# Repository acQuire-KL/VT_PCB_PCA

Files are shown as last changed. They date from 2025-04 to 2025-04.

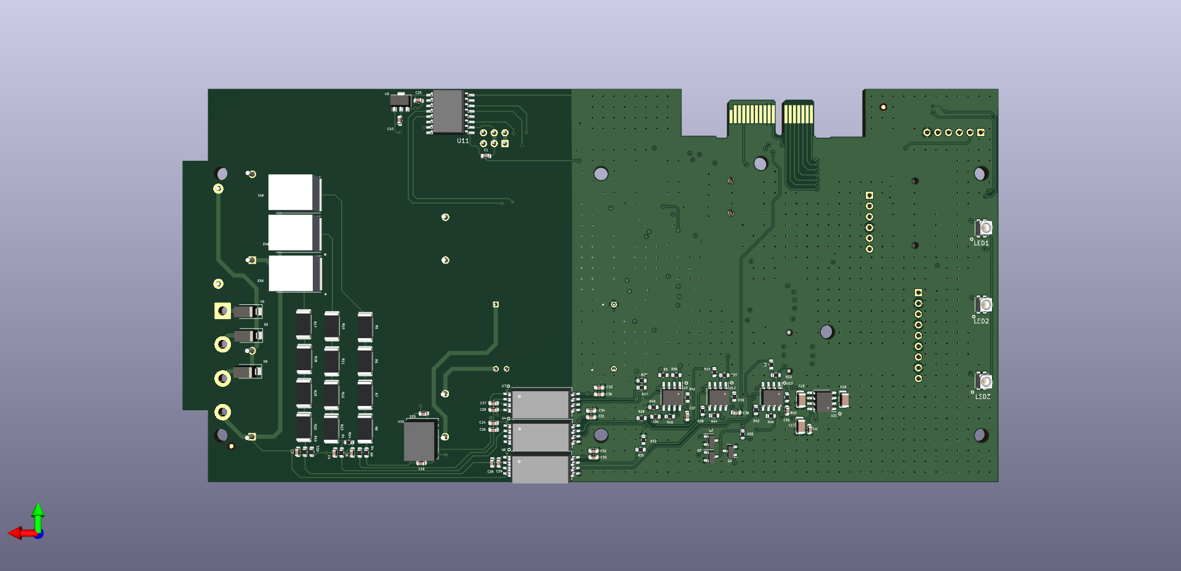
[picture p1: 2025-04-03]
_From_Cornel/H2Scan_Main_V5_4-pin - Cornel 15-04-2024/Main_V5 Cornel 15-04-2024/H2Scan_Main_v50_bottom_view.png

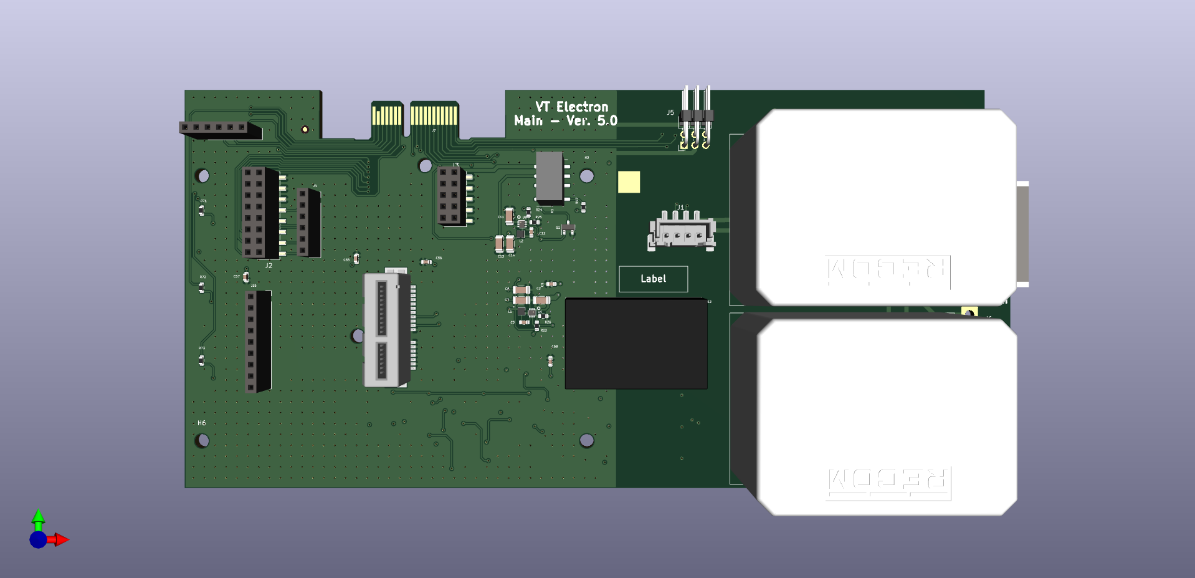
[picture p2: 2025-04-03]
_From_Cornel/H2Scan_Main_V5_4-pin - Cornel 15-04-2024/Main_V5 Cornel 15-04-2024/H2Scan_Main_v50_top_view.png

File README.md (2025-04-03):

HISTORY

<table>
  <tr>
    <td valign="top">
      Description
    </td>
    <td valign="top">
      <table border="1">
        <tr>
          <th style="font-size: 14px; font-weight: bold;">Name</th>
          <th style="font-size: 14px; font-weight: bold;">PCB</th>
          <th style="font-size: 14px; font-weight: bold;">PCA</th>
          <th style="font-size: 14px; font-weight: bold;">Date</th>
          <th style="font-size: 14px; font-weight: bold;">Comments</th>
        </tr>
        <tr>
          
          <td style="font-size: 12px;">ADE</td>
          <td style="font-size: 12px;">4901-30030-05</td>
          <td style="font-size: 12px;">3901-30030-05</td>
          <td style="font-size: 12px;">2024-09-20</td>
          <td style="font-size: 12px;">Current MFG Revisions</td>
        </tr>
        <tr>
          <td style="font-size: 12px;"></td>
          <td style="font-size: 12px;">2025-03-28</td>
          <td style="font-size: 12px;">00 --> 01 to add new circuit sections</td>
        </tr>
        <tr>
          <td style="font-size: 12px;">PCB_1001_00</td>
          <td style="font-size: 12px;">2025-03-01</td>
          <td style="font-size: 12px;">Initial release</td>
        </tr>
      </table>
    </td>
  </tr>
</table>

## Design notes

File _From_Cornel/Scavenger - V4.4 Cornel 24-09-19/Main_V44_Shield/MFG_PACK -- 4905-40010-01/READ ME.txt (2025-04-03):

PCB 4905-40010-01 is FR4, no Cu, Back Silkscreen only.

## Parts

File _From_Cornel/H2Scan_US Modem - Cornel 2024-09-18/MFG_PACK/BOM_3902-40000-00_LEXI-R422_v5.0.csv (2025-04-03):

VTPN | Reference | Value | Datasheet | Footprint | Qty | DNP
4200-00010-00 | BT1 | HLC1520-3P | ~ | Battery:HLC1520-3P | 1
4106-00080-00 | C1,C2,C3,C15 | 47p | ~ | Capacitor_SMD:C_0603_1608Metric | 4
4106-00020-00 | C4,C8,C10,C12 | 100n | ~ | Capacitor_SMD:C_0603_1608Metric | 4
4128-00100-00 | C5,C6 | TAJD477K006RNJ | ~ | Capacitor_Tantalum_SMD:CP_EIA-7361-38_AVX-V_Pad2.18x3.30mm_HandSolder | 2
4106-00070-00 | C7 | 15p | ~ | Capacitor_SMD:C_0603_1608Metric | 1
4106-00060-00 | C9 | 68p | ~ | Capacitor_SMD:C_0603_1608Metric | 1
4106-00015-00 | C11 | 10n | ~ | Capacitor_SMD:C_0603_1608Metric | 1
-- mixed values -- | C13,C14,J1 | DNP | ~ | -- mixed values -- | 3
4724-00010-00 | D1 | SMF05C.TCT |  | Diode_SMD:SC70-6 | 1
 | FID1,FID2,FID3,FID4 | Fiducial | ~ | Fiducial:Fiducial_1mm_Mask2mm | 4 | DNP
 | H1 | MountingHole | ~ | MountingHole:MountingHole_2.5mm Simpla | 1 | DNP
4402-00020-00 | J2 | Conn_02x05_Counter_Clockwise | ~ | Connector_PinHeader_2.54mm:PinHeader_2x05_P2.54mm_Vertical_SMD_MOD | 1
4402-00030-00 | J3 | Conn_02x08_Counter_Clockwise | ~ | Connector_PinHeader_2.54mm:PinHeader_2x08_P2.54mm_Vertical_SMD_MOD | 1
4753-00010-00 | J4,J5,J6 | Conn_01x01_Male | ~ | TestPoint:TestPoint_Pad_5.1x5.1mm | 3
4414-00020-00 | J11 | 78646-3001 |  | Connector_Molex:MOLEX_78646-3001 | 1
4416-00010-00 | J12 | CONUFL001-SMD-T | ~ | Connector_Coaxial:U.FL_Molex_MCRF_73412-0110_Vertical | 1
4500-00010-00 | Q3,Q8 | PDTC143XT |  | Package_TO_SOT_SMD:SOT-23 | 2
4006-00001-00 | R1,R4 | 0 | ~ | Resistor_SMD:R_0603_1608Metric | 2
4006-00020-00 | R2 | 220 | ~ | Resistor_SMD:R_0603_1608Metric | 1
4006-00150-00 | R3 | 4k7 | ~ | Resistor_SMD:R_0603_1608Metric | 1
 | TP1 | Eticheta | ~ | Symbol:Eticheta | 1 | DNP
4702-01010-00 | U1 | TPS22967DSGR | TPS22967DSGR | Package_SON:WSON-8-1EP_2x2mm_P0.5mm_EP0.9x1.6mm_ThermalVias | 1
4702-00010-00 | U2 | TXB0104RUT | http://www.ti.com/lit/ds/symlink/txb0104.pdf | Package_DFN_QFN:Texas_R_PUQFN-N12 | 1
4300-01010-00 | FB1 | FerriteBead_Small | ~ | Inductor_SMD:L_Walsin_WLFM201209x | 1
4752-01010-00 | D2 | LED | ~ | LED_SMD:LED_0805_2012Metric | 1
 | TP4 | TestPoint | ~ | TestPoint:TestPoint_Pad_D1.5mm | 1 | DNP
4716-00020-00 | M1 | LEXI-R422 |  | ublox:LEXI | 1

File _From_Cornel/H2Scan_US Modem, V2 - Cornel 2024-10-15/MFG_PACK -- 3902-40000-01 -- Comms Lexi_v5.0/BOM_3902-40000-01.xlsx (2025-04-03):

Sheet: ECO History
RefDes | VTPN | Action | ECO | Date | Description | Comment
 |  | Initial Release |  | 2024-09-20 | Initial Release of Prototype for R&D
C16 | 4106-00020-00 | Add | 24-ECO-007 | 2024-10-15 | CAP 0603 (1608_m), 100n, 10%, 16V X7R
C17 | 4106-00020-00 | Add | 24-ECO-007 | 2024-10-15 | CAP 0603 (1608_m), 100n, 10%, 16V X7R
U2 | 4702-00010-00 | Remove | 24-ECO-007 | 2024-10-15 | IC, 4-Bit Bi-Directional Tri-State Level Shifter, Auto Detect Direction, 12-UQFN
Q1 | 4500-00010-00 | Add | 24-ECO-007 | 2024-10-15 | TRN, BJT NPN - Pre-Biased R1=4K7 R2=10K, 50 V 100mA 250mW, SMD, TO-236AB (SOT-23)
Q2 | 4500-00010-00 | Add | 24-ECO-007 | 2024-10-15 | TRN, BJT NPN - Pre-Biased R1=4K7 R2=10K, 50 V 100mA 250mW, SMD, TO-236AB (SOT-23)
Q4 | 4500-00010-00 | Add | 24-ECO-007 | 2024-10-15 | TRN, BJT NPN - Pre-Biased R1=4K7 R2=10K, 50 V 100mA 250mW, SMD, TO-236AB (SOT-23)
Q5 | 4500-00010-00 | Add | 24-ECO-007 | 2024-10-15 | TRN, BJT NPN - Pre-Biased R1=4K7 R2=10K, 50 V 100mA 250mW, SMD, TO-236AB (SOT-23)
Q6 | 4500-00010-00 | Add | 24-ECO-007 | 2024-10-15 | TRN, BJT NPN - Pre-Biased R1=4K7 R2=10K, 50 V 100mA 250mW, SMD, TO-236AB (SOT-23)
PCB1 | 4902-40000-01 | Remove | 24-ECO-007 | 2024-10-15 | PCB, Scavenger GSM, U-Blox (72x25.5mm, 4-Layers, Cu, ENIG), ver 5.0
PCB1 | 4902-40000-02 | Add | 24-ECO-007 | 2024-10-15 | PCB, Scavenger GSM, U-Blox (72x25.5mm, 4-Layers, Cu, ENIG), ver 5.0.2

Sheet: Scavenger BOM
Seq | Level | VTPN | Description | ECO | Qty | UoM | RefDes | Populate | BOM Notes | Type | LifeCycle | MFG | MPN | Per Assy. | Unit € | Value € | Vendor | Parts Master Notes | MOQ | Pack Qty | LT
1 | Parent | 3902-40000-01 | PCA, Scavenger - Communications (GSM), U-Blox Lexi, Ver 5.0 | 24-ECO-007 | 1 | ea |  |  |  | Make | Obsolete | ECAS | 0.00 | 1 | 0.0000 | 21.7220 |  | 0.0000 | 0 | 0 | 0
2 | 1 | 4200-00020-00 | CAP, 3v7 39mAh Hybrid Layer Capacitor, 15x20, 3-pin Solder Tags |  | 1 | ea | BT1 |  |  | Buy | Production | LongSing Technology | HPC-1520 | 1 | 2.6969 | 2.6969 | LongSing Technology Group | 0.0000 | 500 | 500 | 0
3 | 1 | 4106-00080-00 | CAP 0603 (1608_m), 47p, 5%, 50V C0G |  | 4 | ea | C1,C2,C3,C15 |  |  | Buy | Production | Walsin | 0603N470J500CT | 4 | 0.0046 | 0.0184 | 0.0000 | 0.0000 | 4000 | 4000 | 0
4 | 1 | 4106-00020-00 | CAP 0603 (1608_m), 100n, 10%, 16V X7R | 24-ECO-007 | 6 | ea | C4,C8,C10,C12,C16,C17 |  |  | Buy | Production | Darfon | C1005X7R104KETS | 6 | 0.0005 | 0.0029 | Schukat | 0.0000 | 4000 | 4000 | 0
5 | 1 | 4128-00100-00 | CAP 2917 (7343_m), 470u, 10%, 6v3 Tant |  | 2 | ea | C5,C6 |  |  | Buy | Production | Kyocera AVX | TAJD477K006RNJ | 2 | 0.5600 | 1.1200 | ECAS | 0.0000 | 500 | 500 | 0
6 | 1 | 4106-00070-00 | CAP 0603 (1608_m), 15p, 5%, 50V C0G |  | 1 | ea | C7 |  |  | Buy | Production | Walsin | 0603N150J500CT | 1 | 0.0044 | 0.0044 | 0.0000 | 0.0000 | 4000 | 4000 | 0
7 | 1 | 4106-00060-00 | CAP 0603 (1608_m), 68p, 5%, 50V C0G |  | 1 | ea | C9 |  |  | Buy | Production | Samsung | CL10C680JB8NNNC | 1 | 0.0074 | 0.0074 | 0.0000 | 0.0000 | 4000 | 4000 | 0
8 | 1 | 4106-00015-00 | CAP 0603 (1608_m), 10n, 10%, 50V X7R |  | 1 | ea | C11 |  |  | Buy | Production | Darfon | C1608X7R103KGTS | 1 | 0.0021 | 0.0021 | Schukat | 0.0000 | 4000 | 4000 | 0
9 | 1 | 4106-00000-00 | CAP 0603 Place Holder |  | 2 | ea | C13,C14 | DNP |  | Reference Item | Production | None | None | 2 | 0.0000 |  |  | 0.0000 | 0 | 0 | 0
10 | 1 | 4724-00010-00 | TVS, 5-Ch, 12.5V Clamp 8A (8/20µs) Ipp, SC-70-6 |  | 1 | ea | D1 |  |  | Buy | Production | Semtech | SMF05C.TCT | 1 | 0.2448 | 0.2448 | ECAS | 0.0000 | 3000 | 0 | 0
11 | 1 | 4752-01010-00 | LED, Green 523nm, 3.2V, 0805 (2012 Metric) |  | 1 | ea | D2 |  |  | Buy | Production | Dialight | 598-8181-102F | 1 | 0.4775 | 0.4775 | 0.0000 | 0.0000 | 100 | 1 | 0
12 | 1 | 4300-01010-00 | FB, 220 Ohms, Ferrite Bead, 0603 (1608 Metric), 2A 50mOhm |  | 1 | ea | FB1 |  |  | Buy | Production | Murata | BLM18EG221SN1D | 1 | 0.0526 | 0.0526 | 0.0000 | 0.0000 | 4000 | 4000 | 0
13 | 1 | 4000-00000-00 | Test point / Mounting Hole / Fudicials / Non Component on PCB |  | 4 | ea | FID1,FID2,FID3,FID4 | DNP |  | Reference Item | Production | none | none | 4 | 0.0000 |  |  | 0.0000 | 0 | 0 | 0
14 | 1 | 4000-00000-00 | Test point / Mounting Hole / Fudicials / Non Component on PCB |  | 1 | ea | H1 | DNP |  | Reference Item | Production | none | none | 1 | 0.0000 |  |  | 0.0000 | 0 | 0 | 0
15 | 1 | 4402-00020-00 | CON, 2x5-pin, Straight, SMD, B2B Male Header, P=2.54mm, 3A |  | 1 | ea | J2 |  |  | Buy | Production | Amphenol FCI | 95278-102B10LF | 1 | 0.3668 | 0.3668 | ECAS | 0.0000 | 5000 | 0 | 0
16 | 1 | 4402-00030-00 | CON, 2x8-pin, Straight, SMD, B2B Male Header, P=2.54mm, 3A |  | 1 | ea | J3 |  |  | Buy | Production | Amphenol FCI | 95278-102B16LF | 1 | 0.4309 | 0.4309 | ECAS | 0.0000 | 1 | 0 | 0
17 | 1 | 4753-00010-00 | HDW, Cable Clamp, SMD, 5x5x2mm, Ø1.0 ~ 1.5mm |  | 3 | ea | J4,J5,J6 |  | • Pay attention to orientation as it is possible to have four. | Buy | Production | Harwin | S8111-46R | 3 | 0.1331 | 0.3994 | Digikey | 0.0000 | 1500 | 1500 | 0
18 | 1 | 4414-00020-00 | CON, 6-Pos MicroSIM Cage, Push-Pull, No Detect, SMD |  | 1 | ea | J11 |  |  | Buy | Production | Molex | 78646-3001 | 1 | 0.7900 | 0.7900 | ECAS | RFQ before next build | 57 | 1 | 0
19 | 1 | 4416-00010-00 | CON, U.FL (UMCC) Jack, Male Pin 50Ohm SMD |  | 1 | ea | J12 |  |  | Buy | Production | TE Connectivity | 2337019-1 | 1 | 0.0061 | 0.0061 | ECAS | 0.0000 | 55 | 1 | 0
20 | 1 | 4716-00020-00 | MDM, Cellular, LTE-M and NBIoT module with 2G fallback for global use, 133 pin LGA |  | 1 | ea | M1 |  | • Pay attention to orientation as it is possible to have four. | Buy | Production | u-Blox | LEXI-R422-01B-00 | 1 | 14.3653 | 14.3653 | Alpha Micro | 0.0000 | 1000 | 1000 | 0
21 | 1 | 4500-00010-00 | TRN, BJT NPN - Pre-Biased R1=4K7 R2=10K, 50 V 100mA 250mW, SMD, TO-236AB (SOT-23) | 24-ECO-007 | 3 | ea | Q1,Q3,Q8 |  |  | Buy | Production | Nexperia | PDTC143XT | 3 | 0.0270 | 0.0811 | ECAS | 0.0000 | 3000 | 0 | 0
22 | 1 | 4500-00010-00 | TRN, BJT NPN - Pre-Biased R1=4K7 R2=10K, 50 V 100mA 250mW, SMD, TO-236AB (SOT-23) | 24-ECO-007 | 4 | ea | Q2,Q4,Q5,Q6 |  |  | Buy | Production | Nexperia | PDTC143XT | 4 | 0.0270 | 0.1082 | ECAS | 0.0000 | 3000 | 0 | 0
23 | 1 | 4006-00001-00 | RES 0603 (1608_m), 0R (Jumper), 1%, 1/10W, Thick Film |  | 2 | ea | R1,R4 |  |  | Buy | Production | Vishay Dale | CRCW06030000Z0EA | 2 | 0.0009 | 0.0018 | Schukat | 0.0000 | 5000 | 5000 | 0
24 | 1 | 4006-00020-00 | RES 0603 (1608_m), 220R, 1%, 1/10W, Thick Film |  | 1 | ea | R2 |  |  | Buy | Production | Vishay | CRCW0603220RFKEA | 1 | 0.0010 | 0.0010 | ECAS | 0.0000 | 5000 | 0 | 0
25 | 1 | 4006-00150-00 | RES 0603 (1608_m), 4K7, 1%, 1/10W, Thick Film |  | 1 | ea | R5 |  |  | Buy | Production | Vishay | CRCW06034K70FKEA | 1 | 0.0012 | 0.0012 | Schukat | 0.0000 | 5000 | 5000 | 0
26 | 1 | 4006-00170-00 | RES 0603 (1608_m), 10K, 1%, 1/10W, Thick Film |  | 4 | ea | R6,R7,R8,R9 |  |  | Buy | Production | Vishay | CRCW060310K0FKEA | 4 | 0.0005 | 0.0019 | Schukat | 0.0000 | 5000 | 5000 | 0
27 | 1 | 4000-00000-00 | Test point / Mounting Hole / Fudicials / Non Component on PCB |  | 1 | ea | TP1 | DNP |  | Reference Item | Production | none | none | 1 | 0.0000 |  |  | 0.0000 | 0 | 0 | 0
28 | 1 | 4000-00000-00 | Test point / Mounting Hole / Fudicials / Non Component on PCB |  | 1 | ea | TP4 | DNP |  | Reference Item | Production | none | none | 1 | 0.0000 |  |  | 0.0000 | 0 | 0 | 0
29 | 1 | 4702-01010-00 | IC, Power Switch/Driver 1:1 N-Channel 4A 8-WSON (2x2) |  | 1 | ea | U1 |  |  | Buy | Production | TI | TPS22967DSGT | 1 | 0.5414 | 0.5414 | 0.0000 | 0.0000 | 250 | 250 | 0
30 | 1 | 4902-40000-02 | PCB, Scavenger GSM, U-Blox (72x25.5mm, 4-Layers, Cu, ENIG), ver 5.0.2 | 24-ECO-007 | 1 | ea | PCB1 |  |  | Buy | Obsolete | EMS Approved | 0.00 | 1 | 0.9200 | 0.9200 | 0.0000 | 0.0000 | 0 | 0 | 0

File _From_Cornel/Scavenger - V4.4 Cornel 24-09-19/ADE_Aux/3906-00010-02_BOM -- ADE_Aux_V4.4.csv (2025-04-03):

Reference | VTPN | Value | Datasheet | Footprint | Qty | DNP
FID1,FID2,FID3,FID4 | 4000-00000-00 | Fiducial | ~ | Fiducial:Fiducial_1mm_Mask2mm | 4 | DNP
J2 | 4000-00000-00 | Bus_PCI_Express_x1_MOD | http://www.ritrontek.com/uploadfile/2016/1026/20161026105231124.pdf#page=63 | Connector_PCBEdge:BUS_PCIexpress_x1 | 1 | DNP
J15 | 4000-00000-00 | MUAS100-8-C-E | ~ | Connector_PinHeader_2.54mm:PinHeader_1x08_P2.54mm_Vertical | 1 | DNP
TP1 | 4000-00000-00 | Eticheta | ~ | Symbol:Eticheta | 1 | DNP
C4,C8,C10,C12 | 4004-00000-00 | DNP | ~ | Capacitor_SMD:C_0402_1005Metric | 4
R3,R5,R7,R8,R11,R13,R15,R16,R17,R19,R20,R21 | 4004-00001-00 | 0 | ~ | Resistor_SMD:R_0402_1005Metric | 12
R1,R2 | 4004-00010-00 | 1k | ~ | Resistor_SMD:R_0402_1005Metric | 2
R4,R10,R12,R14 | 4004-00020-00 | 100 | ~ | Resistor_SMD:R_0402_1005Metric | 4
R6,R9,R18,R22,R27 | 4004-00100-00 | 30K | ~ | Resistor_SMD:R_0402_1005Metric | 5
R23,R24,R25,R26 | 4004-02000-00 | 137K | ~ | Resistor_SMD:R_0402_1005Metric | 4
C1,C3,C7,C9,C11 | 4104-00020-00 | 22n | ~ | Capacitor_SMD:C_0402_1005Metric | 5
C2,C5,C6,C13,C14,C15,C16,C17,C19,C21,C23,C27,C28,C29,C30,C31 | 4104-00100-00 | 100n | ~ | Capacitor_SMD:C_0402_1005Metric | 16
C18,C20,C22,C24,C25,C26 | 4112-00100-00 | 10u | ~ | Capacitor_SMD:C_1206_3216Metric | 6
J1 | 4408-00010-00 | MUAS100-8-C-E | ~ | Connector_JST:A2501-SR08-XH8AWB | 1
U4 | 4520-00030-00 | MC7660DR2 | http://www.ti.com/lit/ds/symlink/lmc7660.pdf | Package_SO:SO-8_3.9x4.9mm_P1.27mm | 1
U2 | 4706-00030-00 | ADE9430 |  | Package_QFP:ADE9430 | 1
U1,U3 | 4708-00010-00 | TLV2186IDSGR | -- mixed values -- | Package_SON:WSON-8-1EP_2x2mm_P0.5mm_EP0.9x1.6mm_ThermalVias | 2
Y2 | 4712-00020-00 | ECS-5032MV-245.7-BN-TR |  | Oscillator:OSC_ECS-5032MV-245.7-BN-TR | 1
U99 | 4726-00010-00 | NC7SZ126M5X |  | Buffer3S:Buffer3S | 1

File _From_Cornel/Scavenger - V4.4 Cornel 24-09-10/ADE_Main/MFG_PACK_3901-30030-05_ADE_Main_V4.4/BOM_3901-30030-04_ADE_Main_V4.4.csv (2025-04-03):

VTPN | Reference | Value | Datasheet | Footprint | Qty | DNP
4104-00020-00 | C1,C3,C7,C9,C11 | 22n | ~ | Capacitor_SMD:C_0402_1005Metric | 5
4112-00100-00 | C18,C20,C22,C24,C25,C26 | 10u | ~ | Capacitor_SMD:C_1206_3216Metric | 6
-- mixed values -- | C2,C5,C6,C13,C14,C15,C16,C17,C19,C21,C23,C27,C28,C29,C30 | 100n | ~ | -- mixed values -- | 15
4104-00000-00 | C4,C8,C10,C12 | DNP | ~ | Capacitor_SMD:C_0402_1005Metric | 4
 | FID1,FID2,FID3,FID4 | Fiducial | ~ | Fiducial:Fiducial_1mm_Mask2mm | 4
 | J2 | Bus_PCI_Express_x1_MOD | http://www.ritrontek.com/uploadfile/2016/1026/20161026105231124.pdf#page=63 | Connector_PCBEdge:BUS_PCIexpress_x1 | 1
4408-00010-00 | J1,J15 | MUAS100-8-C-E | ~ | -- mixed values -- | 2
4004-00010-00 | R1,R2 | 1k | ~ | Resistor_SMD:R_0402_1005Metric | 2
4004-02000-00 | R23,R24,R25,R26 | 137K | ~ | Resistor_SMD:R_0402_1005Metric | 4
4004-00001-00 | R3,R5,R7,R8,R11,R13,R15,R16,R17,R19,R20,R21 | 0 | ~ | Resistor_SMD:R_0402_1005Metric | 12
4004-00020-00 | R4,R10,R12,R14 | 100 | ~ | Resistor_SMD:R_0402_1005Metric | 4
4004-00100-00 | R6,R9,R18,R22 | 30K | ~ | Resistor_SMD:R_0402_1005Metric | 4
 | TP1 | Eticheta | ~ | Symbol:Eticheta | 1
4706-00030-00 | U2 | ADE9430 |  | Package_QFP:ADE9430 | 1
4520-00030-00 | U4 | MC7660DR2 | http://www.ti.com/lit/ds/symlink/lmc7660.pdf | Package_SO:SO-8_3.9x4.9mm_P1.27mm | 1
4708-00010-00 | U1,U3 | TLV2186IDSGR | -- mixed values -- | Package_SON:WSON-8-1EP_2x2mm_P0.5mm_EP0.9x1.6mm_ThermalVias | 2
4712-00020-00 | Y2 | ECS-5032MV-245.7-BN-TR |  | Oscillator:OSC_ECS-5032MV-245.7-BN-TR | 1

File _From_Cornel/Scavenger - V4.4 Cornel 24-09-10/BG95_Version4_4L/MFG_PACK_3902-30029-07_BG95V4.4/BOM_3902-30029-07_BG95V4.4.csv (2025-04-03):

VTPN | Reference | Value | Datasheet | Footprint | Qty | DNP
4200-00020-00 | BT1 | HLC1520-3P | ~ | Battery:HLC1520-3P | 1
4106-00040-00 | C1,C2,C3,C9,C10 | 33p | ~ | -- mixed values -- | 5
4106-00020-00 | C4,C7,C8 | 100n | ~ | -- mixed values -- | 3
4128-00100-00 | C5,C6 | TAJD477K006RNJ | ~ | Capacitor_Tantalum_SMD:CP_EIA-7361-38_AVX-V_Pad2.18x3.30mm_HandSolder | 2
4106-00010-00 | C11,C12 | 10p | ~ | Capacitor_SMD:C_0603_1608Metric_Pad1.05x0.95mm_HandSolder | 2
-- mixed values -- | C13,C14,J1 | DNP | ~ | -- mixed values -- | 3
4724-00010-00 | D1 | SMF05C.TCT |  | Diode_SMD:SC70-6 | 1
 | FID1,FID2,FID3,FID4 | Fiducial | ~ | Fiducial:Fiducial_1mm_Mask2mm | 4 | DNP
 | H1 | MountingHole | ~ | MountingHole:MountingHole_2.5mm Simpla | 1 | DNP
4402-00020-00 | J2 | Conn_02x05_Counter_Clockwise | ~ | Connector_PinHeader_2.54mm:PinHeader_2x05_P2.54mm_Vertical_SMD_MOD | 1
4402-00030-00 | J3 | Conn_02x08_Counter_Clockwise | ~ | Connector_PinHeader_2.54mm:PinHeader_2x08_P2.54mm_Vertical_SMD_MOD | 1
4753-00010-00 | J4,J5,J6 | Conn_01x01_Male | ~ | TestPoint:TestPoint_Pad_5.1x5.1mm | 3
4414-00020-00 | J11 | 78646-3001 |  | Connector_Molex:MOLEX_78646-3001 | 1
4416-00010-00 | J12 | CONUFL001-SMD-T | ~ | Connector_Coaxial:U.FL_Molex_MCRF_73412-0110_Vertical | 1
4500-00010-00 | Q1,Q3,Q8 | PDTC143XT |  | Package_TO_SOT_SMD:SOT-23 | 3
4530-00010-00 | Q2 | AO4459 | https://www.onsemi.com/pub/Collateral/FDS9435A-D.PDF | Package_SO:SOIC-8_3.9x4.9mm_P1.27mm | 1
4006-00160-00 | R1 | 15k | ~ | Resistor_SMD:R_0603_1608Metric | 1
4006-00150-00 | R2,R3 | 4k7 | ~ | Resistor_SMD:R_0603_1608Metric | 2
4006-00001-00 | R4 | 0 | ~ | Resistor_SMD:R_0603_1608Metric | 1
 | TP1 | Eticheta | ~ | Symbol:Eticheta | 1 | DNP
4716-00010-00 | U1 | BG95 | 1.1 | BG95:XCVR_BG95M3LA-64-SGNS | 1
4702-00010-00 | U2 | TXB0104RUT | http://www.ti.com/lit/ds/symlink/txb0104.pdf | Package_DFN_QFN:Texas_R_PUQFN-N12 | 1

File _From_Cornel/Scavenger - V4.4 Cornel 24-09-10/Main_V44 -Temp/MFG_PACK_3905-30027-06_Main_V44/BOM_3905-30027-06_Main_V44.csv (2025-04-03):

VTPN | Reference | Value | Datasheet | Footprint | Qty | DNP
4106-00020-00 | C1,C3,C5,C10,C12,C15,C20,C21,C24,C25,C27,C28,C29,C33,C34,C35,C36,C37,C38,C39,C40,C43,C47,C48,C49,C50,C55,C56,C57,C58 | 100n | ~ | Capacitor_SMD:C_0603_1608Metric | 30
4112-00110-00 | C2,C11,C53 | 10uF/16V | ~ | Capacitor_SMD:C_1206_3216Metric | 3
4106-00030-00 | C4,C6,C7 | 1n | ~ | Capacitor_SMD:C_0603_1608Metric | 3
4112-00150-00 | C8,C9,C13,C14 | 22uF/6,3V | ~ | Capacitor_SMD:C_1206_3216Metric | 4
4112-00100-00 | C17,C18,C19 | 10u | ~ | Capacitor_SMD:C_1206_3216Metric | 3
4106-00100-00 | C22,C23,C26,C30,C31,C32 | 1uF | ~ | Capacitor_SMD:C_0603_1608Metric | 6
4106-00010-00 | C41,C44 | 10p | ~ | Capacitor_SMD:C_0603_1608Metric | 2
4106-00100-00 | C42 | 1u | ~ | Capacitor_SMD:C_0603_1608Metric | 1
4106-00015-00 | C45,C46 | 10n | ~ | Capacitor_SMD:C_0603_1608Metric | 2
4106-00050-00 | C51 | 4,7n | ~ | Capacitor_SMD:C_0603_1608Metric | 1
4130-00010-00 | C52 | F862DI224K310ZLH0J | ~ | Capacitor_THT:C_Rect_L24.0mm_W7.0mm_P22.50mm_MKT | 1
4510-00010-00 | D4,D5,D6 | BYG21M-E3/TR | ~ | Diode_SMD:D_SMA | 3
 | FID1,FID2,FID3,FID4 | Fiducial | ~ | Fiducial:Fiducial_1mm_Mask2mm | 4 | DNP
 | H1,H2,H3,H4,H5,H6,H7,H8,H9,H10,H11,H12 | MountingHole | ~ | -- mixed values -- | 12 | DNP
4408-00030-00 | J1 | Conn_01x04_Male | ~ | Connector_JST:A2501-SR04-XH4AWB | 1
4402-10021-00 | J2 | Conn_02x08_Counter_Clockwise | ~ | Connector_PinSocket_2.54mm:PinSocket_2x08_P2.54mm_Vertical_SMD_MOD | 1
4402-10011-00 | J3 | Conn_02x05_Counter_Clockwise | ~ | Connector_PinSocket_2.54mm:PinSocket_2x05_P2.54mm_Vertical_SMD | 1
4401-00050-00 | J4,J13 | Conn_01x06_Female | ~ | Connector_PinSocket_2.54mm:PinSocket_1x06_P2.54mm_Vertical | 2
4400-00015-00 | J5 | DS1022-2*10RF11x3 | ~ | Connector_PinHeader_2.54mm:PinHeader_2x03_P2.54mm_Horizontal | 1
 | J6,J8,J9,J10,J11,J12,J14,J16,J17,J18,J19,J20,J22,J23,J24,J25,J26,J32 | Conn_01x01_Female | ~ | -- mixed values -- | 18 | DNP
 | J7 | Bus_PCI_Express_x1_MOD | http://www.ritrontek.com/uploadfile/2016/1026/20161026105231124.pdf#page=63 | Connector_PCBEdge:BUS_PCIexpress_x1 | 1 | DNP
4412-00040-00 | J15 | DS1002-03-1*36131(9) | ~ | Connector_PinSocket_2.54mm:PinSocket_1x09_P2.54mm_Vertical | 1
4401-00040-00 | J21 | Conn_01x03_Male | ~ | Connector_PinHeader_2.54mm:PinHeader_1x03_P2.54mm_Vertical | 1
4420-20010-00 | J27,J28 | Conn_01x02_Female | ~ | TerminalBlock:TerminalBlock_bornier-2_P5.08mm | 2
4753-00010-00 | J29,J30,J31 | Conn_01x01_Male | ~ | TestPoint:TestPoint_Pad_5.1x5.1mm | 3
4750-00010-00 | K1 | FTR-B4GA003Z-B05 | https://www.fujitsu.com/downloads/MICRO/fcai/relays/ftr-f1.pdf | Relay_SMD:Relay_Fujitsu_FTR-B4GA003 | 1
4300-00010-00 | L1,L2 | 744383130033 |  | Inductanta744:744383130033 | 2
4300-00020-00 | L3 | CBC3225T220MR | ~ | Inductor_SMD:L_1206_3216Metric | 1
4752-00010-00 | LED1,LED2,LED3 | CLM2D-GPC-CB0E0793 |  | LedSMD_Cree:CLM2D-GPC-CB0E0793 | 3
4520-30010-00 | PS1 | RAC15-05SK/480 |  | RAC15:CONV_RAC15-12SK_480 | 1
4520-20010-00 | PS2 | THM_10-0511 |  | THM 10-0511:CONV_THM_10-0511 | 1
4520-20022-00 | PS3 | NXE2S0505MC-R7 | NXE2S0505MC-R7 | NXE2S0505MC-R7:NXE2_SINGLE_SURFACE_MUR | 1
4500-00020-00 | Q1 | DTC143T |  | Package_TO_SOT_SMD:SOT-23 | 1
4500-00010-00 | Q2,Q3,Q4 | DTC143E |  | Package_TO_SOT_SMD:SOT-23 | 3
4006-00030-00 | R1,R4,R16 | 10 | ~ | Resistor_SMD:R_0603_1608Metric | 3
4006-00300-00 | R2,R3,R15,R22,R27,R28,R29,R30,R31,R32,R36,R37,R38,R39,R40,R41,R42,R43,R48,R49,R50 | 3k | ~ | Resistor_SMD:R_0603_1608Metric | 21
4018-01000-00 | R5,R6,R7,R8,R10,R11,R12,R13,R17,R18,R19,R20 | 249k | ~ | Resistor_SMD:R_2512_6332Metric | 12
4006-00040-00 | R9,R14,R21 | 150 | ~ | Resistor_SMD:R_0603_1608Metric | 3
4006-00150-00 | R23,R24 | 4k7 | ~ | Resistor_SMD:R_0603_1608Metric | 2
4006-00130-00 | R25 | 1k3 | ~ | Resistor_SMD:R_0603_1608Metric | 1
4006-00140-00 | R26 | 1k5 | ~ | Resistor_SMD:R_0603_1608Metric | 1
4006-00470-00 | R33 | 47k | ~ | Resistor_SMD:R_0603_1608Metric | 1
4006-00200-00 | R34,R51,R52,R53 | 2k 0.1% | ~ | Resistor_SMD:R_0603_1608Metric | 4
4006-00100-00 | R35 | 1k | ~ | Resistor_SMD:R_0603_1608Metric | 1
4006-00160-00 | R44,R45,R46 | 15k | ~ | Resistor_SMD:R_0603_1608Metric | 3
4006-00010-00 | R47 | 47 | ~ | Resistor_SMD:R_0603_1608Metric | 1
4006-00020-00 | R71,R72,R73 | 220 | ~ | Resistor_SMD:R_0603_1608Metric | 3
4022-00010-00 | RV1,RV2,RV3 | MOVS4032V510 | ~ | MOVS4032V510:MOVS4032V460 | 3
 | TP1 | Eticheta | ~ | Symbol:Eticheta | 1 | DNP
4520-10010-00 | U1,U8 | AP62250Z6 | https://www.diodes.com/assets/Datasheets/AP62250.pdf | Package_TO_SOT_SMD:SOT-563 | 2
4700-00010-00 | U2 | ISO3082DW | http://www.ti.com/lit/ds/symlink/iso3082.pdf | Package_SO:SOIC-16W_7.5x10.3mm_P1.27mm | 1
4708-00021-00 | U3,U12,U13 | LM358 | http://www.ti.com/lit/ds/symlink/lm2904-n.pdf | Package_SO:SO-8_3.9x4.9mm_P1.27mm | 3
4710-00010-00 | U4,U6,U7 | AMC1400QDWLRQ1 |  | AMC1400:AMC1400QDWLRQ1 | 3
4522-00010-00 | U5 | L78L05ACUTR | http://www.st.com/content/ccc/resource/technical/document/datasheet/15/55/e5/aa/23/5b/43/fd/CD00000446.pdf/files/CD00000446.pdf/jcr:content/translations/en.CD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 | Package_TO_SOT_SMD:SOT-89-3 | 1
4700-00030-00 | U9 | 74LVC2G157 | http://www.ti.com/lit/sg/scyt129e/scyt129e.pdf | Package_SO:VSSOP-8_2.4x2.1mm_P0.5mm | 1
4706-00040-00 | U11,U20 | MAX31865ATP+T | MAX31865ATP+T | MAX31865:21-0140L_T2055-5_MXM | 2
4410-00010-00 | U14,U15,U16,U17,U18,U19 | 10061913-100CLF |  | PCI_SMD_MOD:10061913-100CLF | 6
4520-00020-01 | U21 | LM2662MX | http://www.ti.com/lit/ds/symlink/lmc7660.pdf | Package_SO:SO-8_3.9x4.9mm_P1.27mm | 1
4704-00020-00 | U22 | MSP430FR2672TRHBR | MSP430FR2672TRHBR | MSP430FR2672TRHBR:VQFN32_5X5_TEX | 1
4714-00010-00 | Y1 | ECS-.327-6-34B-C-TR | ~ | Crystal:Crystal_SMD_EuroQuartz_EQ161-2Pin_3.2x1.5mm | 1

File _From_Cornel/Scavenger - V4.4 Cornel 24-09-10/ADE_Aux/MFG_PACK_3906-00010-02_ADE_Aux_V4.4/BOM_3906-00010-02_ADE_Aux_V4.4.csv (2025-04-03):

Id | Designator | Footprint | Quantity | Designation | Supplier and ref
1 | R25,R26,R24,R23 | R_0402_1005Metric | 4 | 137K
2 | R18,R9,R6,R22,R27 | R_0402_1005Metric | 5 | 30K
3 | R5,R20,R8,R11,R15,R21,R17,R7,R16,R3,R19,R13 | R_0402_1005Metric | 12 | 0
4 | C11,C3,C7,C9,C1 | C_0402_1005Metric | 5 | 22n
5 | C13,C16,C6,C5,C31,C28,C30,C23,C15,C27,C17,C14,C29,C19,C21 | C_0402_1005Metric | 15 | 100n
6 | FID1,FID4,FID3,FID2 | Fiducial_1mm_Mask2mm | 4 | Fiducial
7 | C26,C18,C25,C20,C22,C24 | C_1206_3216Metric | 6 | 10u
8 | C2 | C_0603_1608Metric | 1 | 100n
9 | C4,C12,C10,C8 | C_0402_1005Metric | 4 | DNP
10 | TP1 | Eticheta | 1 | Eticheta
11 | R4,R14,R10,R12 | R_0402_1005Metric | 4 | 100
12 | U3,U1 | WSON-8-1EP_2x2mm_P0.5mm_EP0.9x1.6mm_ThermalVias | 2 | TLV2186IDSGR
13 | U2 | ADE9430 | 1 | ADE9430
14 | R2,R1 | R_0402_1005Metric | 2 | 1k
15 | U99 | Buffer3S | 1 | NC7SZ126M5X
16 | Y2 | OSC_ECS-5032MV-245.7-BN-TR | 1 | ECS-5032MV-245.7-BN-TR
17 | J1 | A2501-SR08-XH8AWB | 1 | MUAS100-8-C-E
18 | J15 | PinHeader_1x08_P2.54mm_Vertical | 1 | MUAS100-8-C-E
19 | J2 | BUS_PCIexpress_x1 | 1 | Bus_PCI_Express_x1_MOD
20 | U4 | SO-8_3.9x4.9mm_P1.27mm | 1 | MC7660DR2

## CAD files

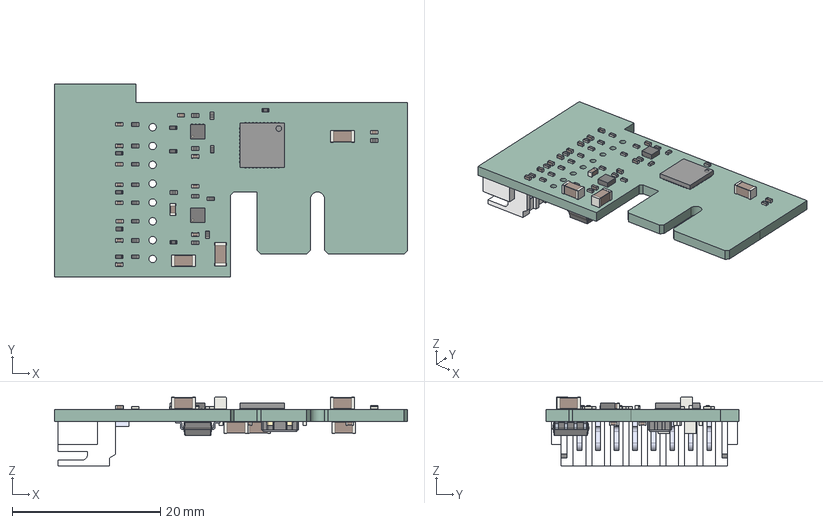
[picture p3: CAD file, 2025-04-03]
_From_Cornel/Scavenger - V4.4 Cornel 24-08-31/Scavenger- V4.4/ADE_Main/4901-30030-05 -- ADE_Main_V4.step
47.6 x 26.0 x 9.25 mm
R_0402_1005Metric x 26
C_0402_1005Metric x 23
C_1206_3216Metric x 6
C_0603_1608Metric
WSON_8_1EP_2x2mm_P05mm_EP09x16mm x 2
ASSEMBLY
ECS-3961slash3963
A2501WR-8P1--3D SMD v2
CQ assembly
ADE_Main_V4_PCB

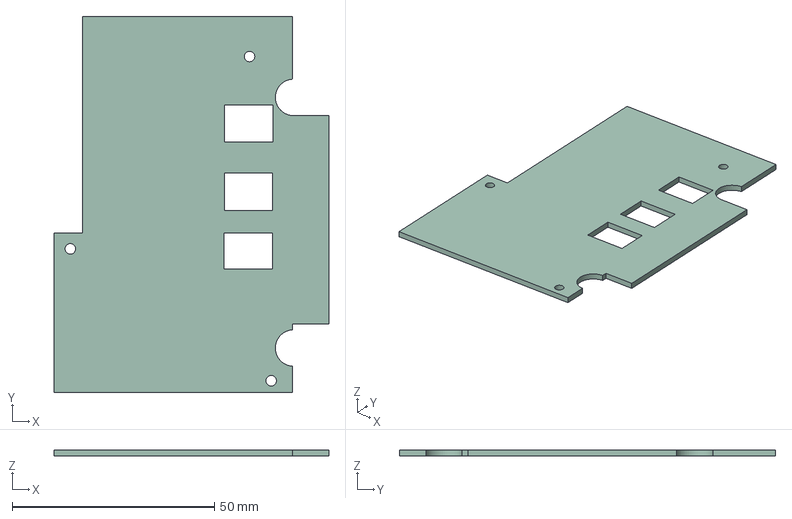
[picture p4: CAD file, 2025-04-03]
_From_Cornel/Scavenger - V4.4 Cornel 24-09-02/Main_V44_Shield/4905-40010-01 -- Main_V4_Shield.step
68.0 x 93.0 x 1.60 mm

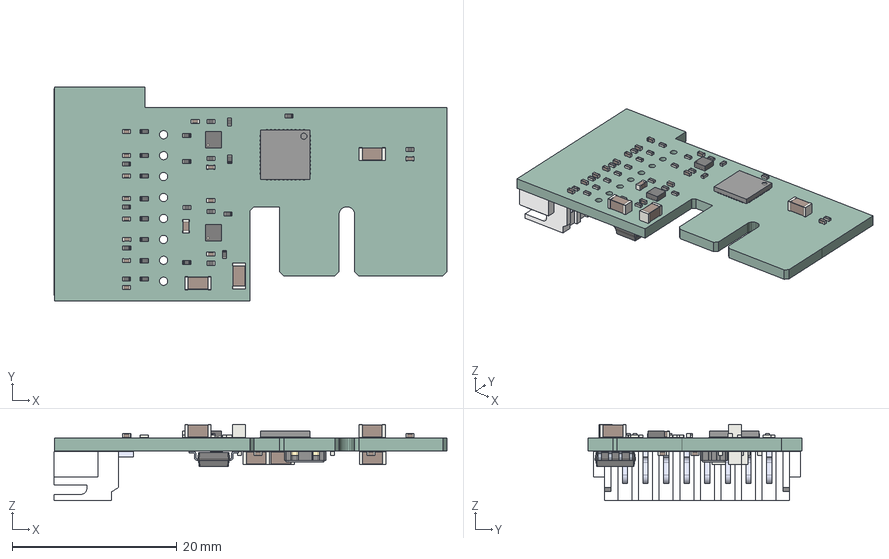
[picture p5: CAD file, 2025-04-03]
_From_Cornel/Scavenger - V4.4 Cornel 24-09-04/ADE_Main/3901-30030-05 -- ADE_Main_V4.4.step
47.7 x 26.0 x 9.23 mm
ADE_Main_V4 PCB

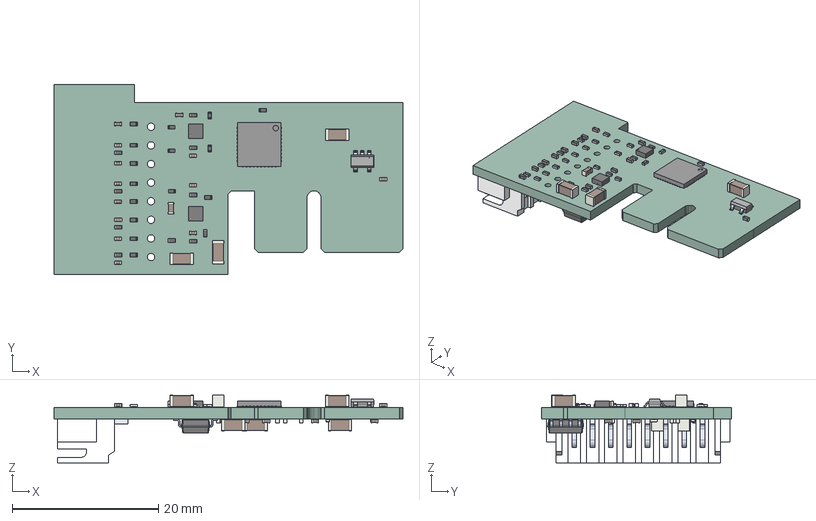
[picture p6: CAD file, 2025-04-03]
_From_Cornel/Scavenger - V4.4 Cornel 24-08-31/Scavenger- V4.4/ADE_Aux/4906-00010-01 -- ADE_Aux_V4.step
47.6 x 26.0 x 9.23 mm
ADE_Aux_V4 PCB

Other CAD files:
_From_Cornel/Scavenger - V4.4 Cornel 24-09-02/ADE_Main/3901-30030-05 -- ADE_Main_V4.step
_From_Cornel/Scavenger - V4.4 Cornel 24-09-04/Main_V44_Shield/4905-40010-01 -- Main_V4_Shield.step
_From_Cornel/Scavenger - V4.4 Cornel 24-09-10/ADE_Main/MFG_PACK_3901-30030-05_ADE_Main_V4.4/3901-30030-05_ADE_Main_V4.4.step
_From_Cornel/Scavenger - V4.4 Cornel 24-09-19/ADE_Main/MFG_PACK -- 3901-30030-05 -- ADE Main, v4.4/3901-30030-05_3D -- ADE_Main_V4.4.step
_From_Cornel/Scavenger - V4.4 Cornel 24-09-19/Main_V44_Shield/MFG_PACK -- 4905-40010-01/4905-40010-01_Main_Shield_V4.step
_From_Cornel/Scavenger - V4.4 Cornel 24-09-02/ADE_Aux/3906-00010-02 -- ADE_Aux_V4.step
_From_Cornel/Scavenger - V4.4 Cornel 24-09-04/ADE_Aux/3906-00010-02 -- ADE_Aux_V4.4.step
_From_Cornel/Scavenger - V4.4 Cornel 24-09-10/ADE_Aux/MFG_PACK_3906-00010-02_ADE_Aux_V4.4/3906-00010-02 -- ADE_Aux_V4.4.step
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

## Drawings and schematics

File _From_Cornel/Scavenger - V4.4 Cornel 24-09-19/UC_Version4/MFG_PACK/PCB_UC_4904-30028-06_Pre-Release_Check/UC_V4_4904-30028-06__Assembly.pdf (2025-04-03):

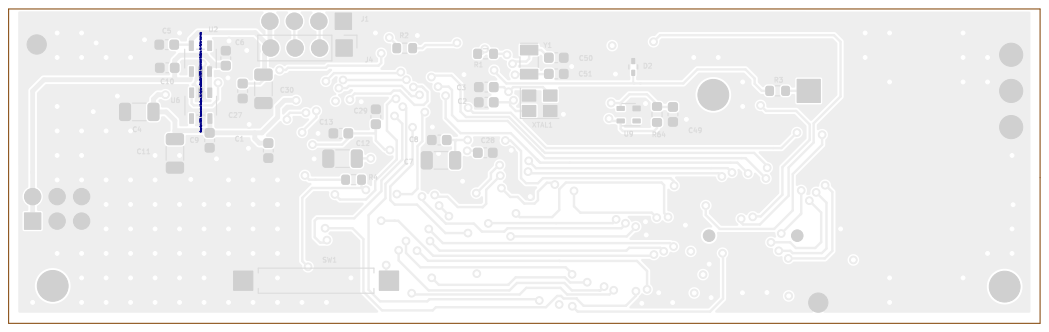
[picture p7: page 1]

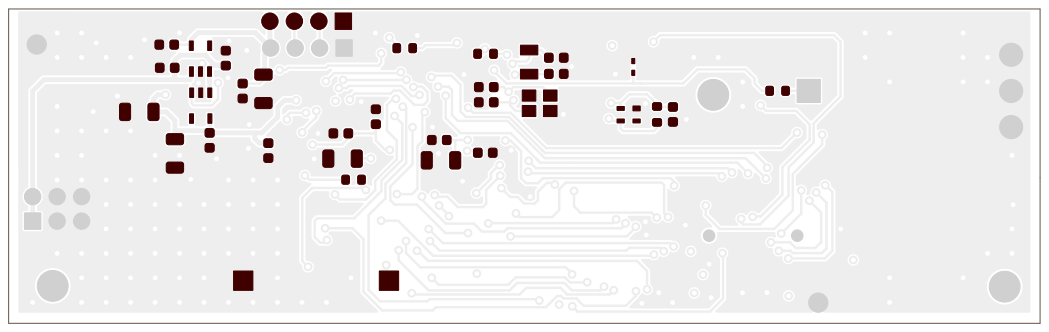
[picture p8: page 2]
D Date: KiCad; E.D.A. 8.0.5 Size: A4; Rev:; Id: 1/1 Title: File: UC_V4_4904-30028-06.kicad_pcb Sheet: Light Colors; PCB; Paste; TOP; Board2Pdf:; Light Colors; TOP -; Page 2/4

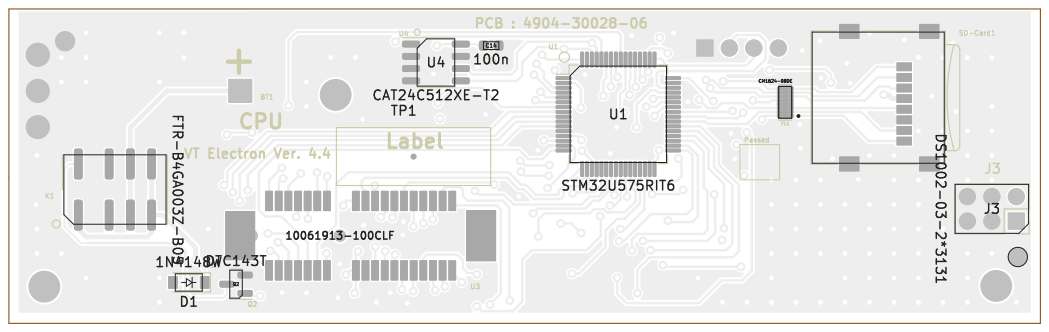
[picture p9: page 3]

Passed PCB : 4904-30028-06 Label CPU

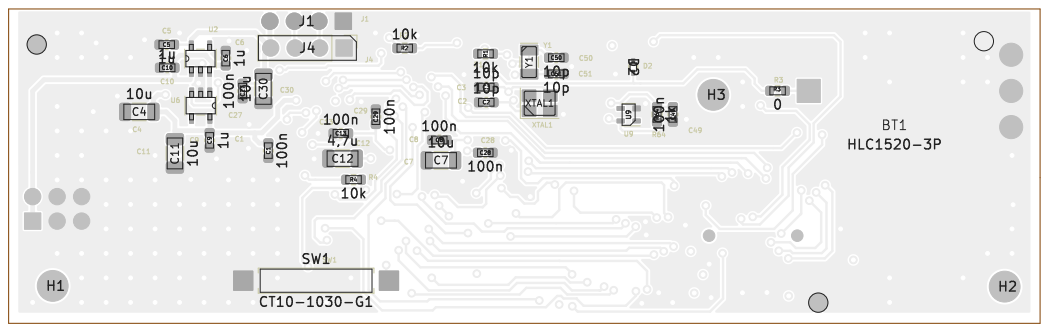
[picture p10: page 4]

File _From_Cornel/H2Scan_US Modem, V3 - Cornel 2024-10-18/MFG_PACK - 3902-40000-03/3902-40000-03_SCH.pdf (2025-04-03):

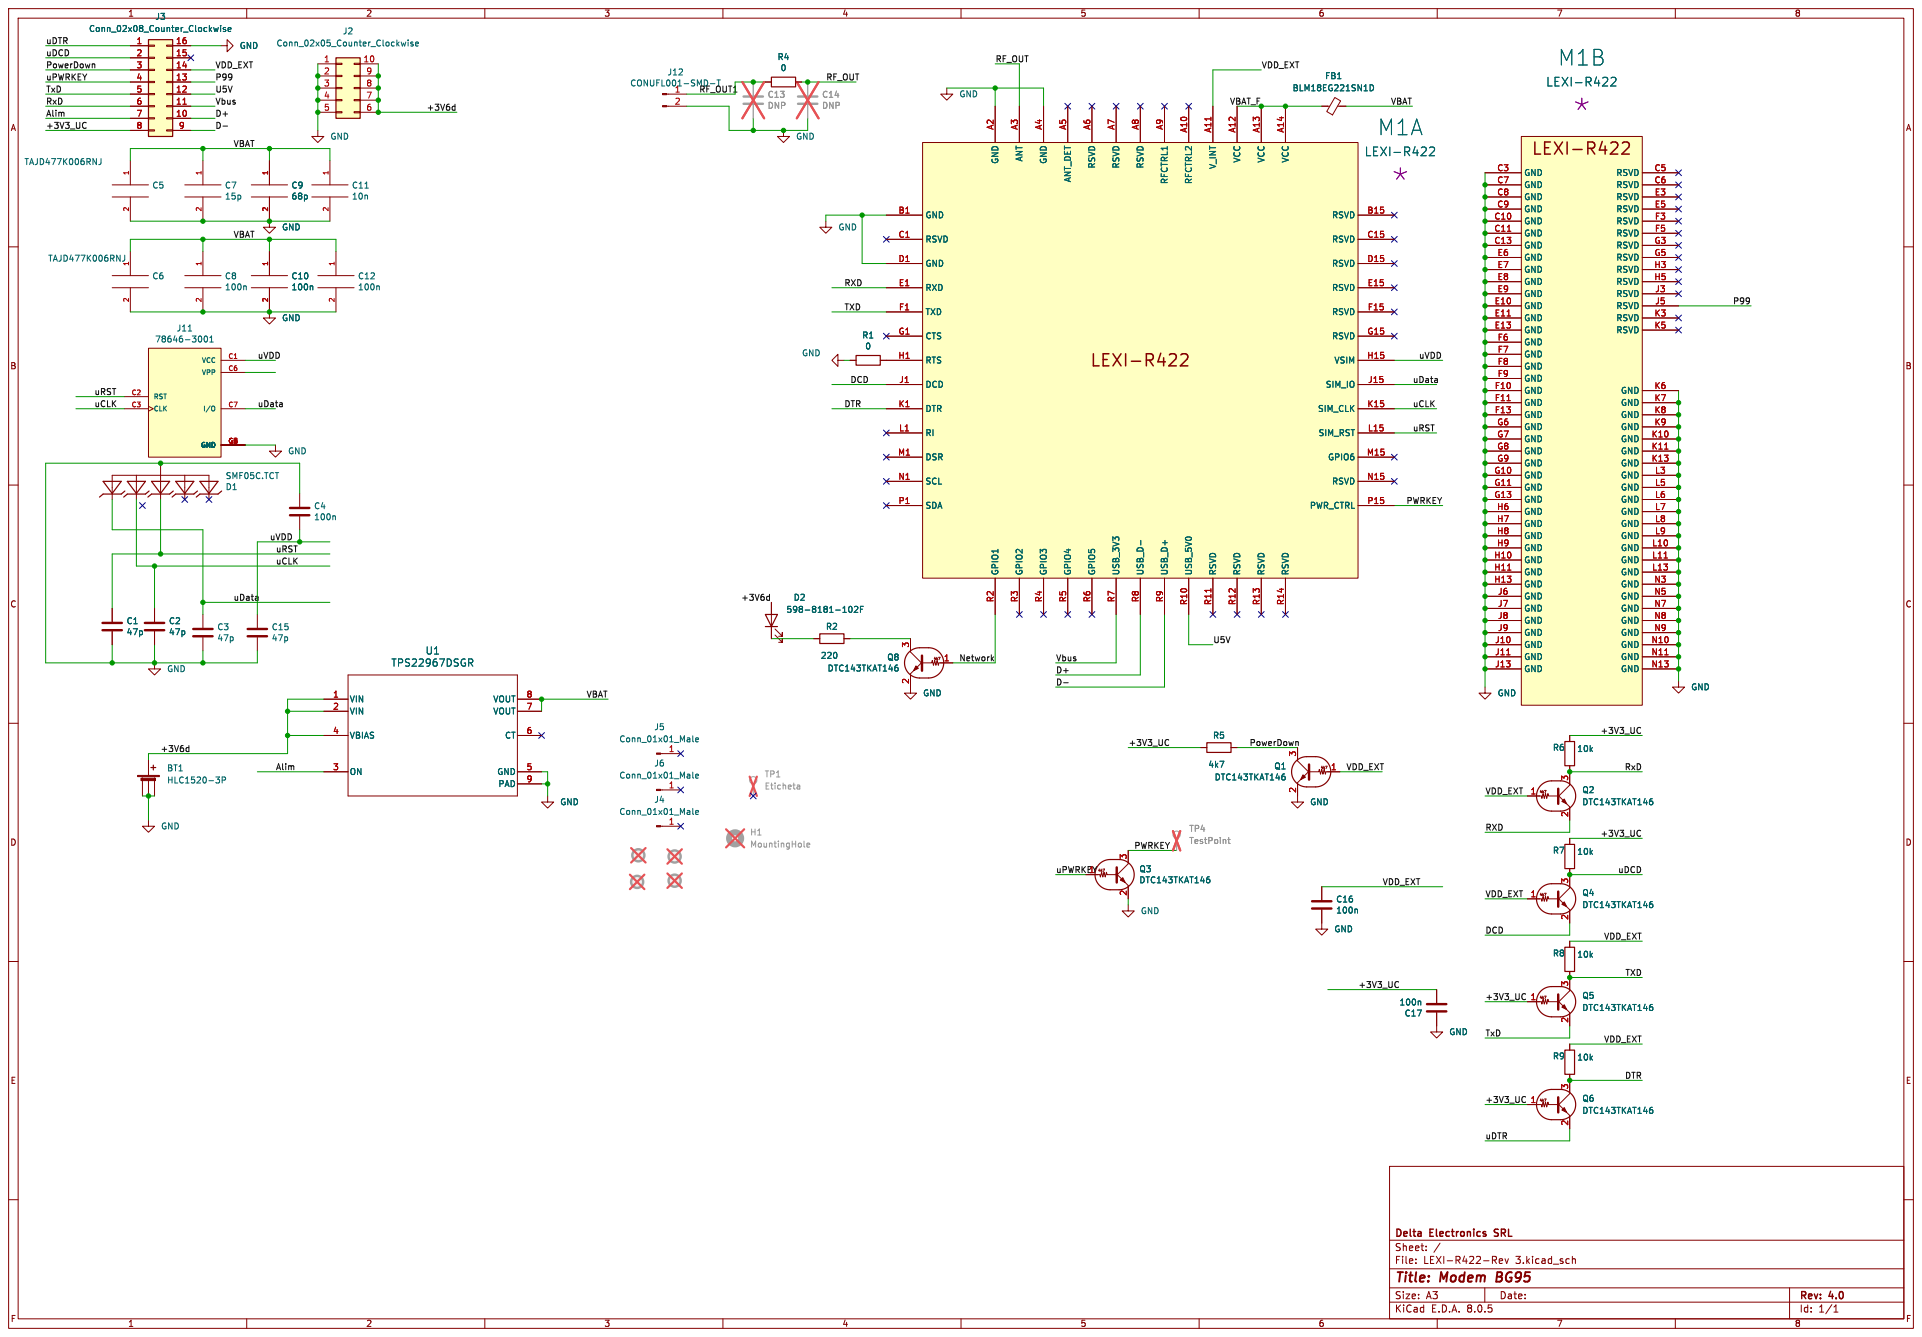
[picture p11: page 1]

1 2 C5 TAJD477K006RNJ LEXI-R422 RFCTRL2 A10 V_INT A11 VCC A12 VCC A13 VCC A14 GND A2 ANT A3 GND A4 ANT_DET A5 RSVD A6 RSVD A7 RSVD A8 RFCTRL1 A9 GND B1 RSVD B15 RSVD C1 RSVD C15 GND D1 RSVD D15 RXD E1 RSVD E15 TXD F1 RSVD F15 CTS G1 RSVD G15 RTS H1 VSIM H15 DCD J1 SIM_IO J15 DTR K1 SIM_CLK K15 RI L1 SIM_RST L15 DSR M1 GPIO6 M15 SCL N1 RSVD N15 SDA P1 PWR_CTRL P15 USB_5V0 R10 RSVD R11 RSVD R12 RSVD R13 RSVD R14 GPIO1 R2 GPIO2 R3 GPIO3 R4 GPIO4 R5 GPIO5 R6 USB_3V3 R7 USB_D- R8 USB_D+ R9

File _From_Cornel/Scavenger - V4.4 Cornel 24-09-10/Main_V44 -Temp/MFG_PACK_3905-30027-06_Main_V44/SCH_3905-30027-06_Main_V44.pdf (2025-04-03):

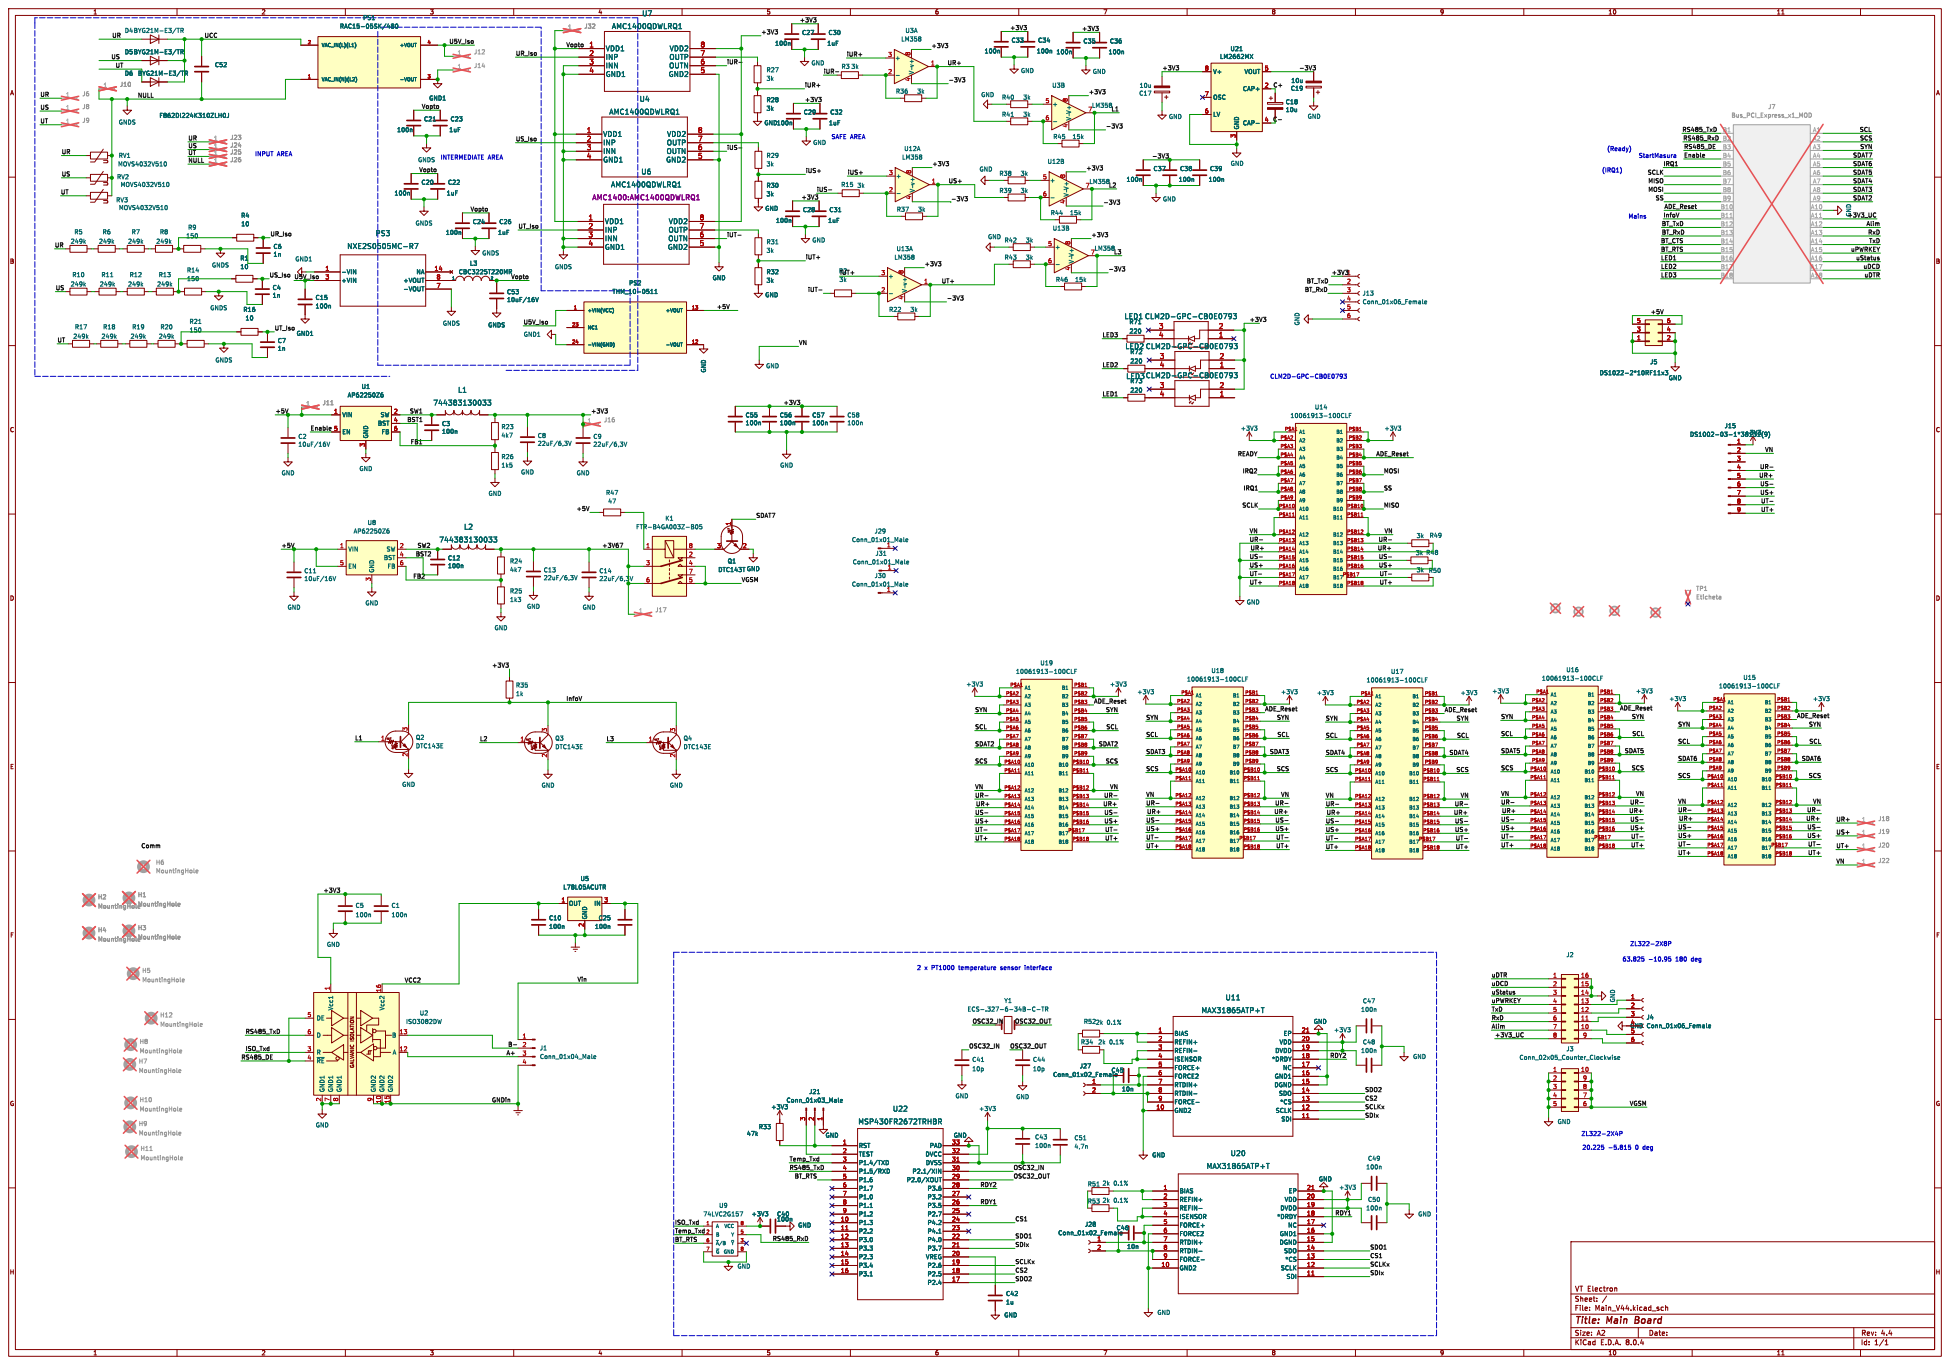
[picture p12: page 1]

SS US+ UT- SCL SDAT2

3 BST 4 EN 5 FB 6 U8 AP62250Z6 GND

SCS US+ UT- VN

UR+ US- UT+ US+ CS2 SDO2 US- UR+

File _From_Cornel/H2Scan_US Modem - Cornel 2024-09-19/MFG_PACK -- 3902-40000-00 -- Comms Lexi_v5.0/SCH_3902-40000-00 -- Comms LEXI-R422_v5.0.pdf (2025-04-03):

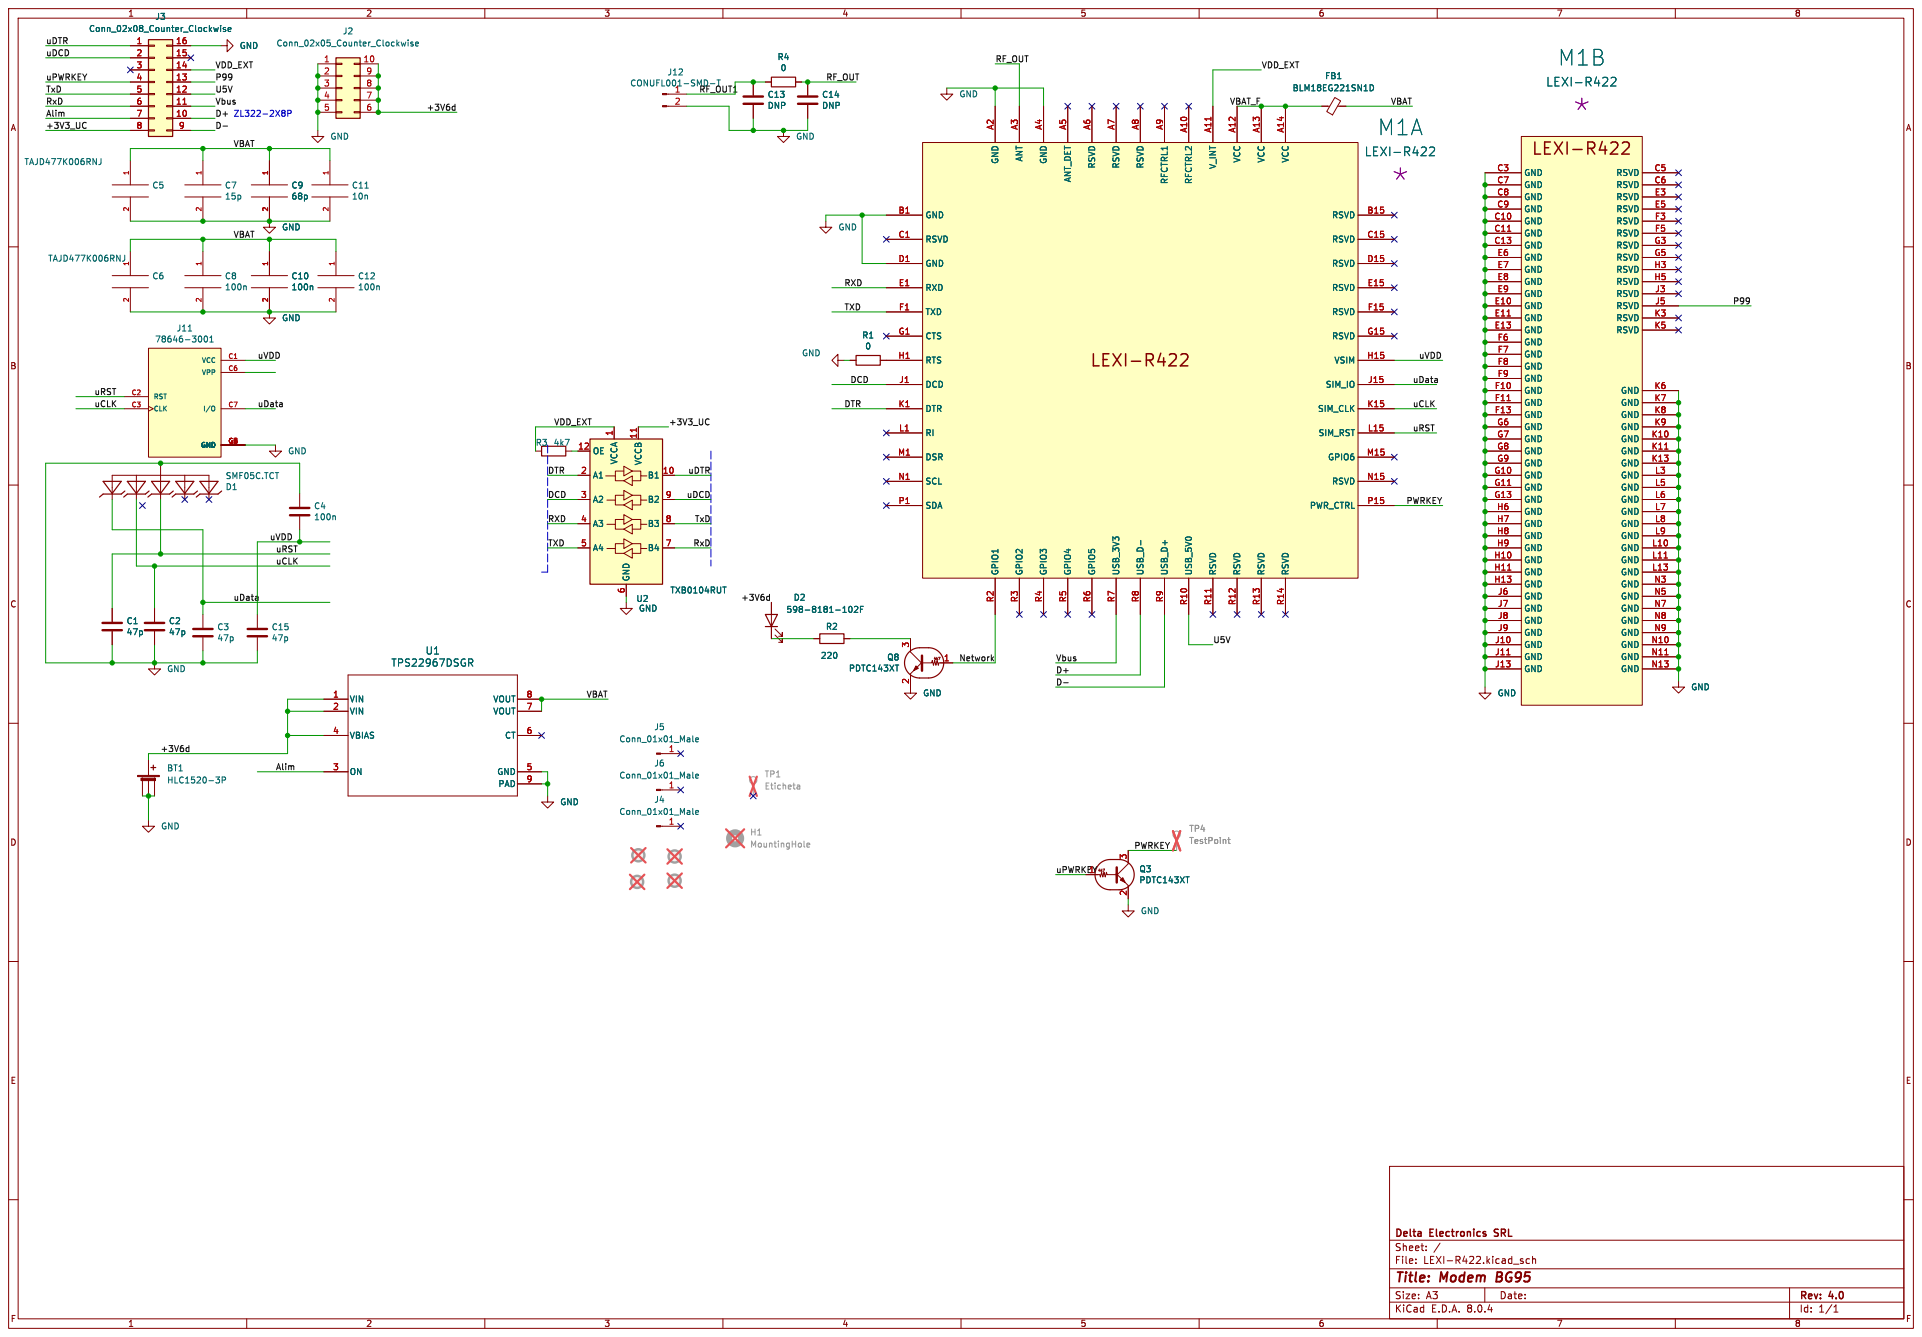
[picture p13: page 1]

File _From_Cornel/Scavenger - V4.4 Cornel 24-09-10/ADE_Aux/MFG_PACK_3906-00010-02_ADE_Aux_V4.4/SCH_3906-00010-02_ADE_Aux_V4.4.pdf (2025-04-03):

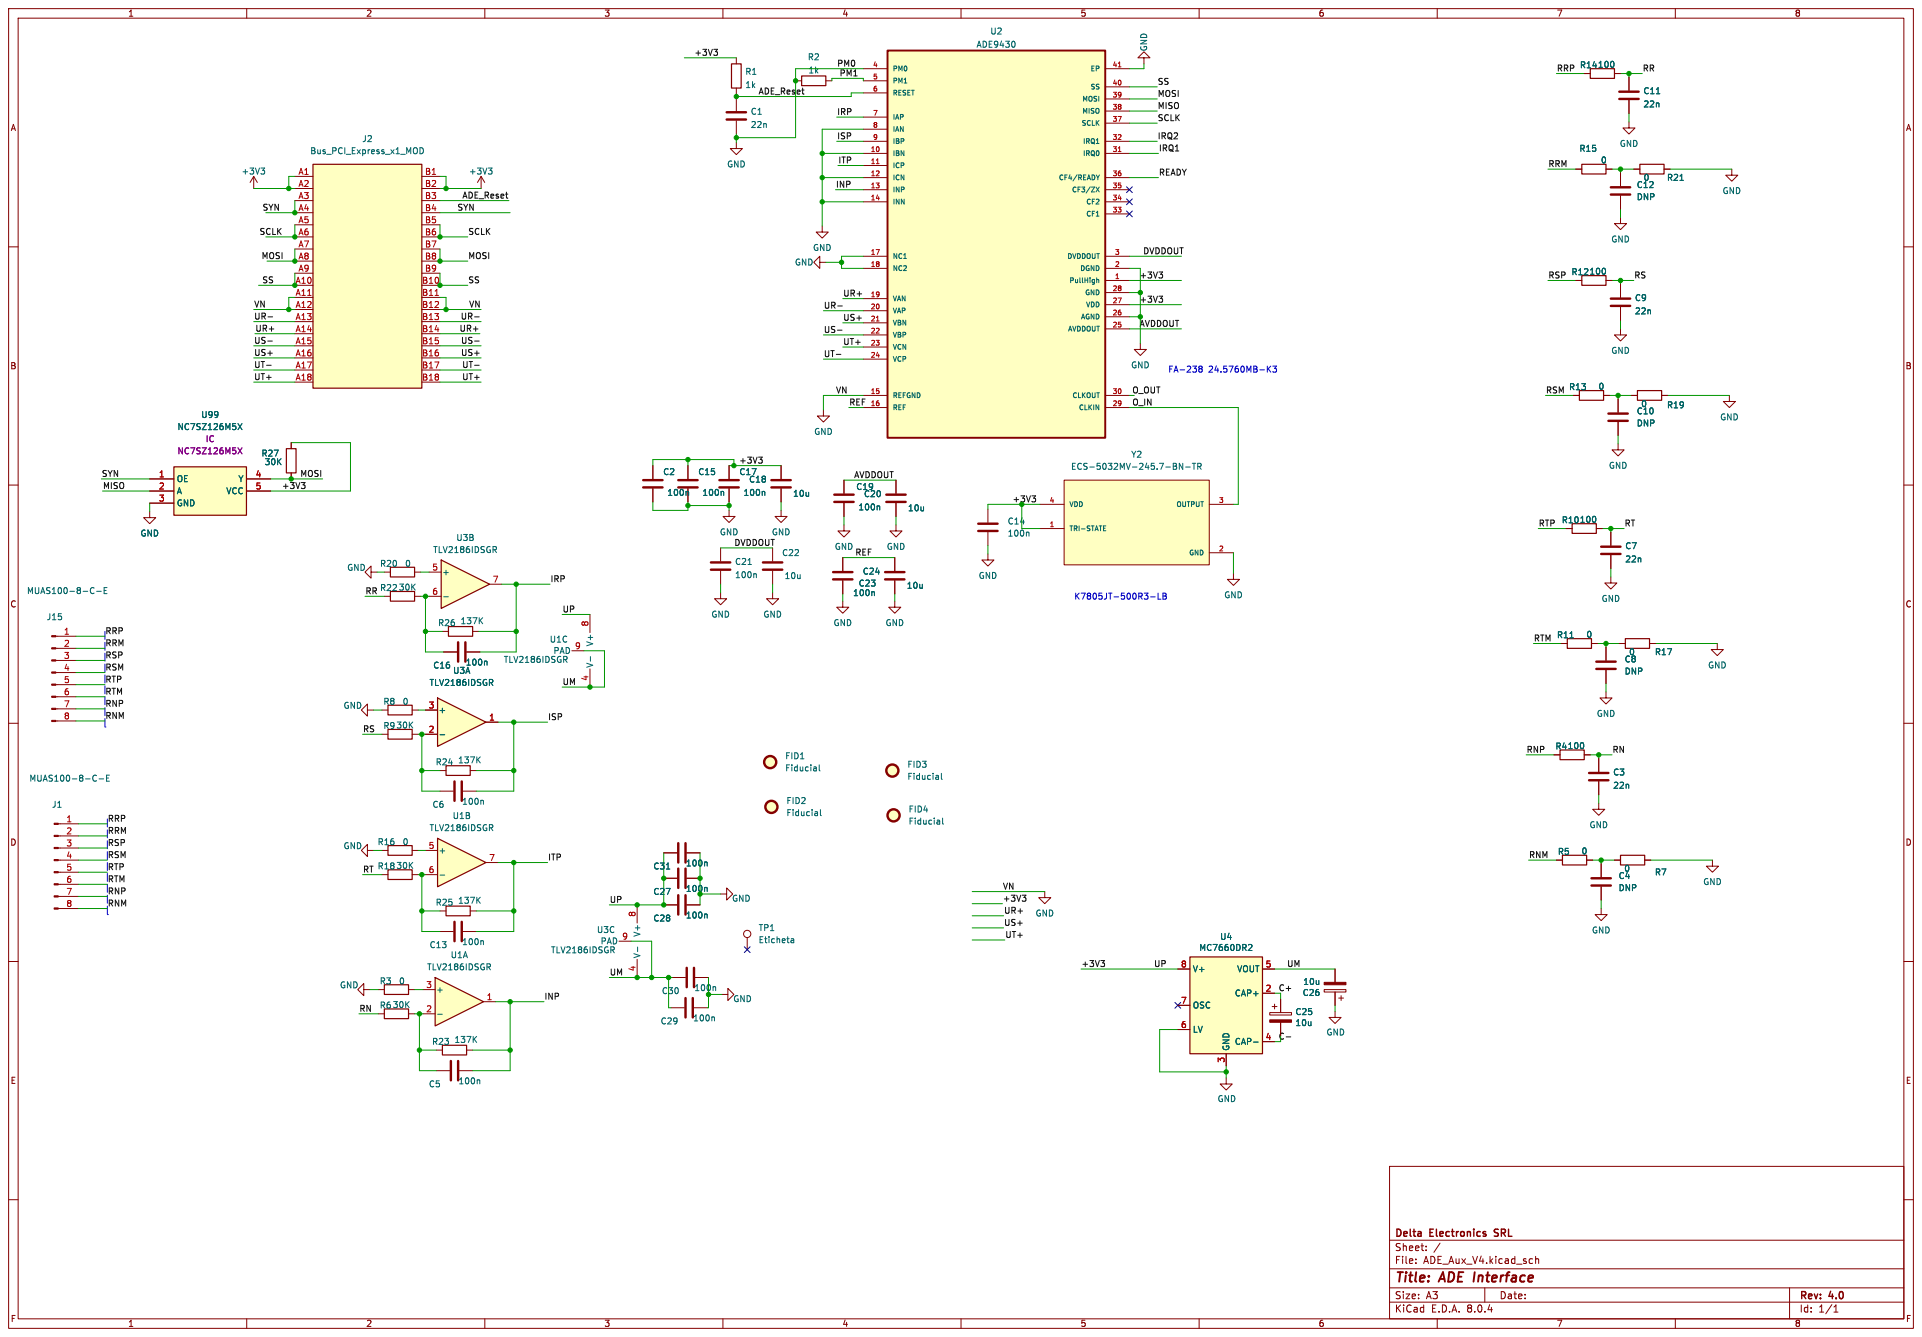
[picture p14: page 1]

DVDDOUT UR- US- UR+

Id: 1/1 Title: ADE Interface

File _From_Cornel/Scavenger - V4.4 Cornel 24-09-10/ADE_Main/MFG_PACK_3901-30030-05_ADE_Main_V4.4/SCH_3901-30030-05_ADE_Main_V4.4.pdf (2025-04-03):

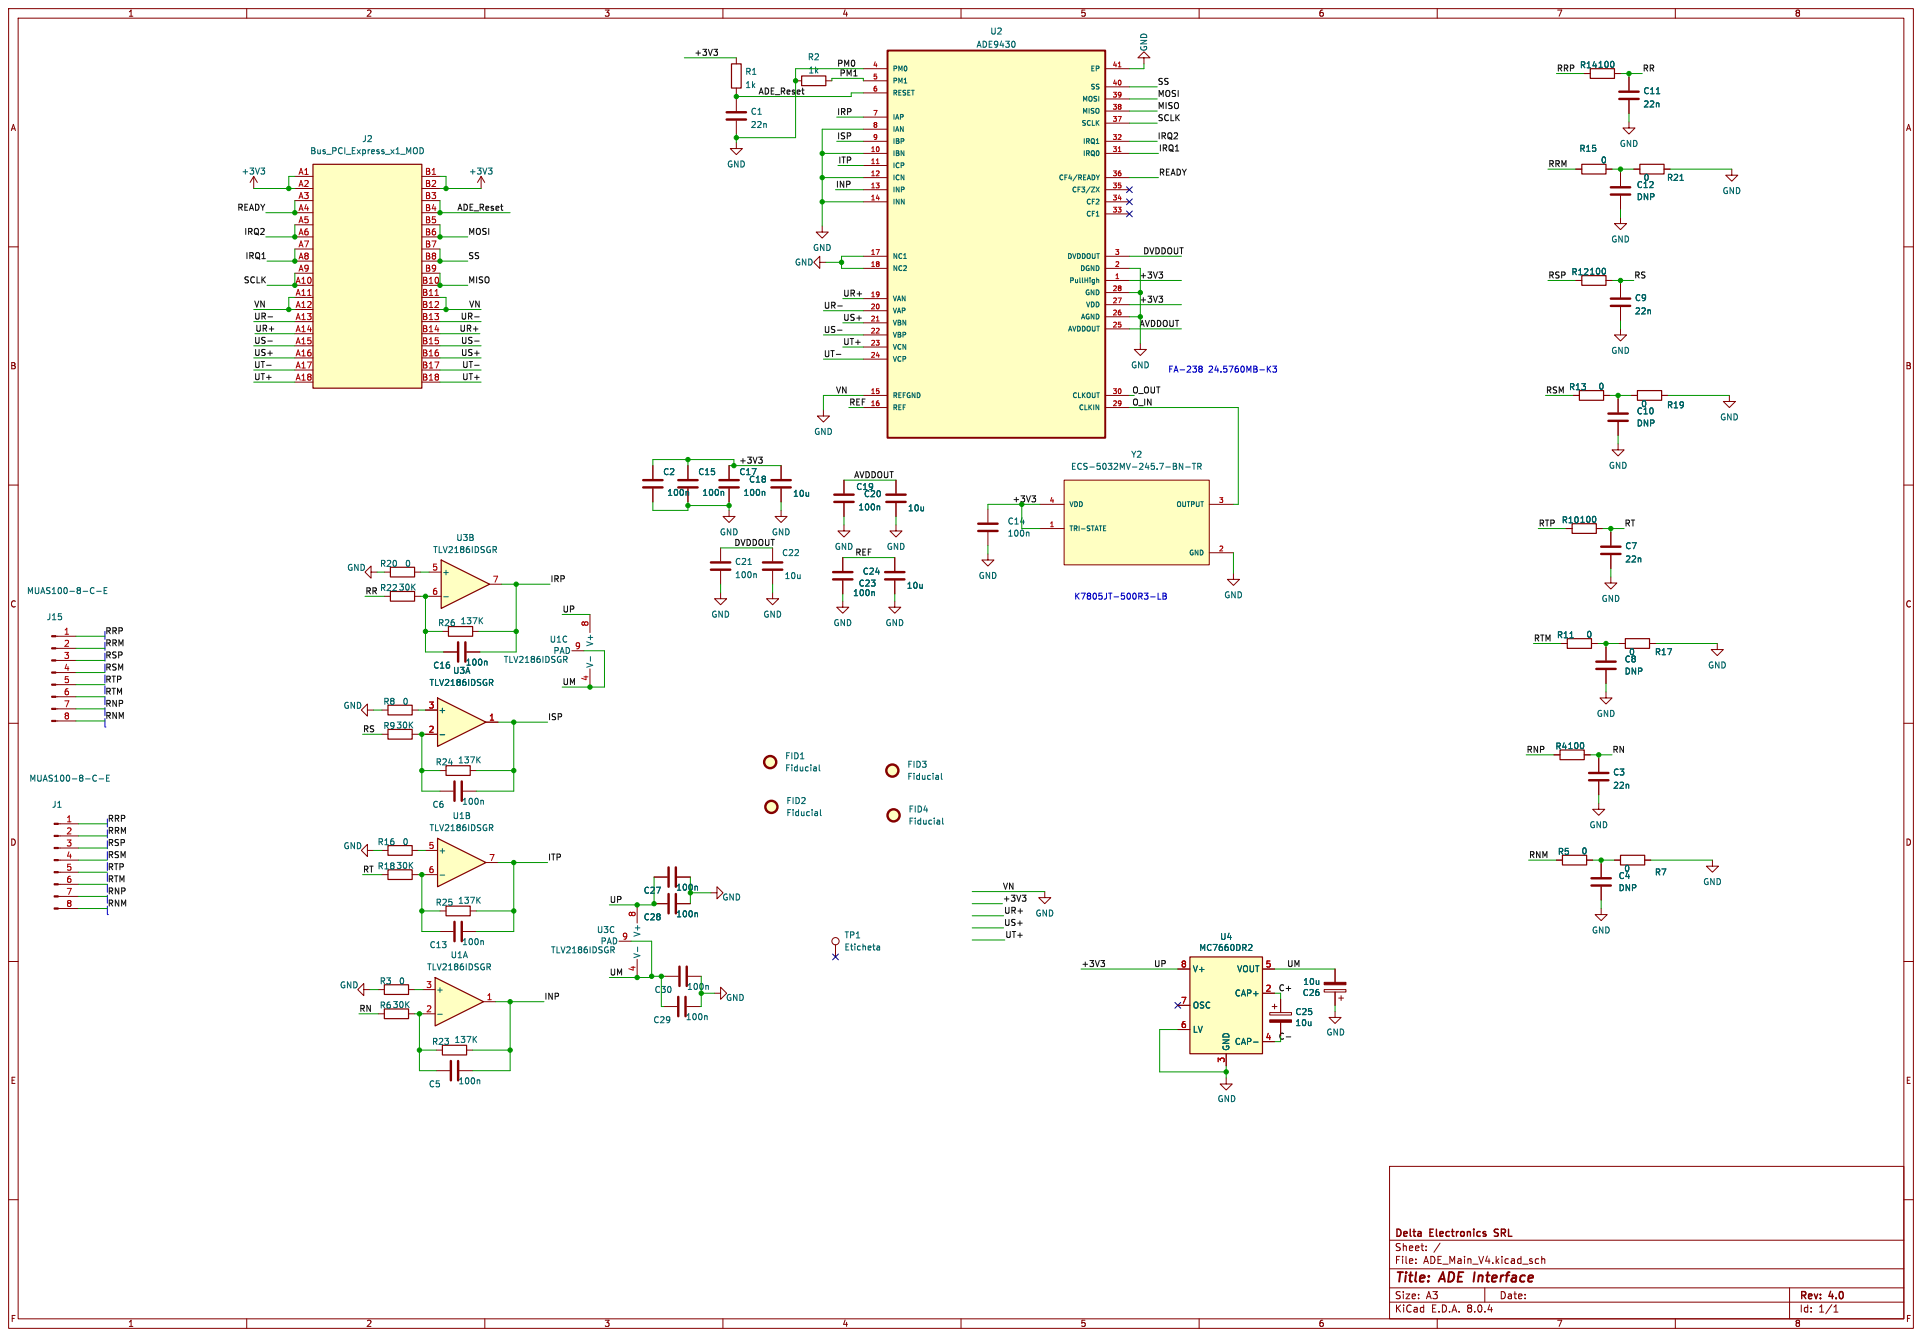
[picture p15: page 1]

Id: 1/1 Title: ADE Interface

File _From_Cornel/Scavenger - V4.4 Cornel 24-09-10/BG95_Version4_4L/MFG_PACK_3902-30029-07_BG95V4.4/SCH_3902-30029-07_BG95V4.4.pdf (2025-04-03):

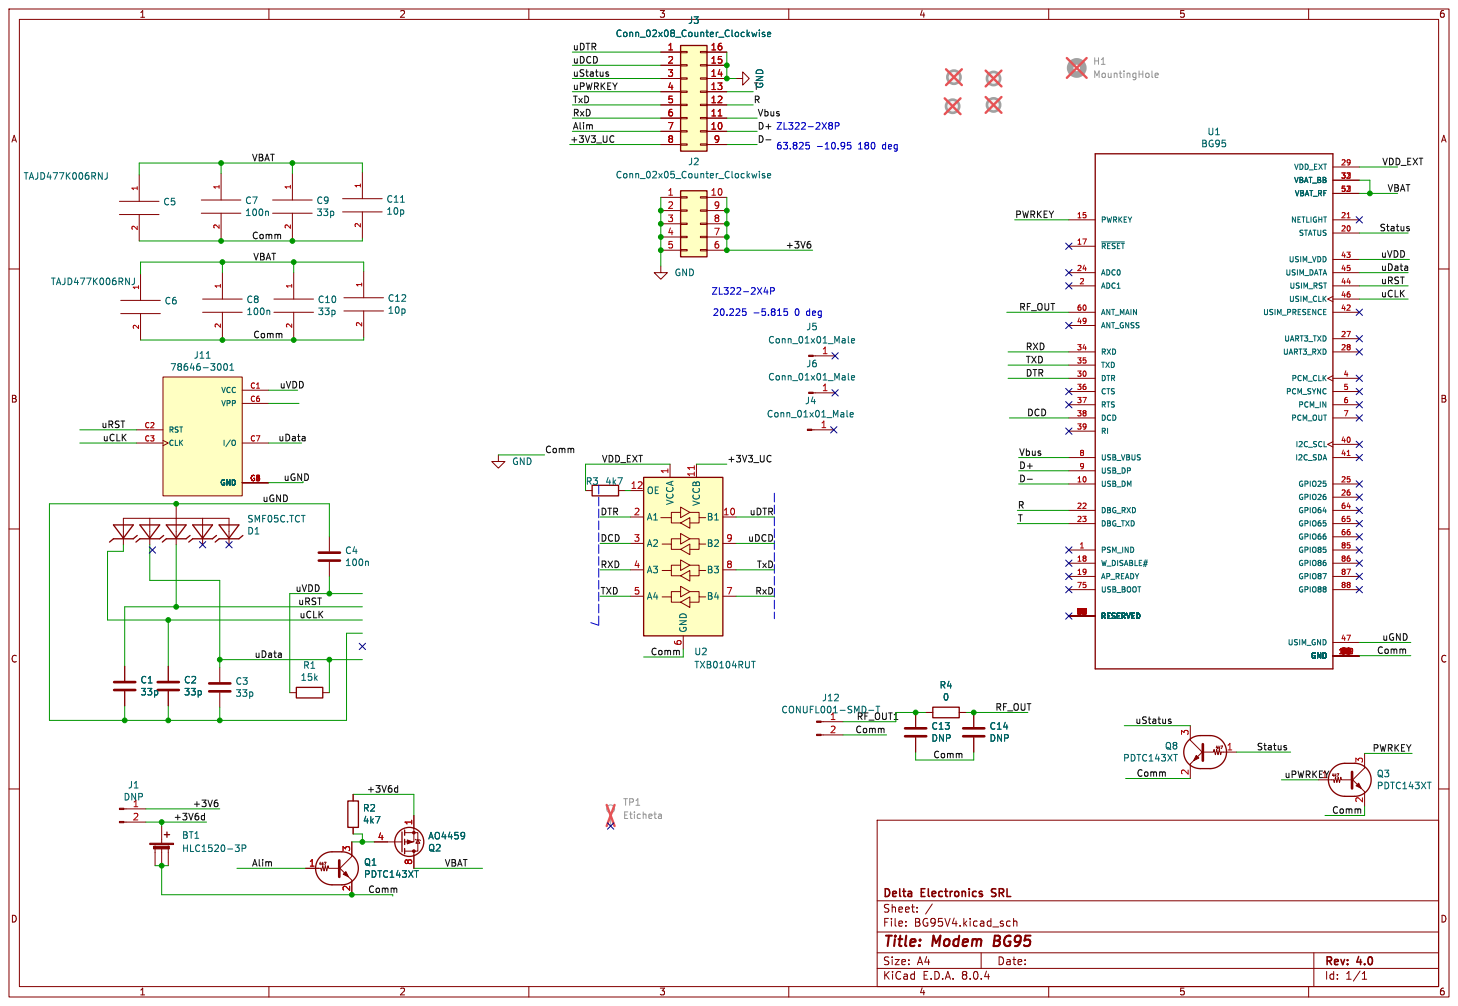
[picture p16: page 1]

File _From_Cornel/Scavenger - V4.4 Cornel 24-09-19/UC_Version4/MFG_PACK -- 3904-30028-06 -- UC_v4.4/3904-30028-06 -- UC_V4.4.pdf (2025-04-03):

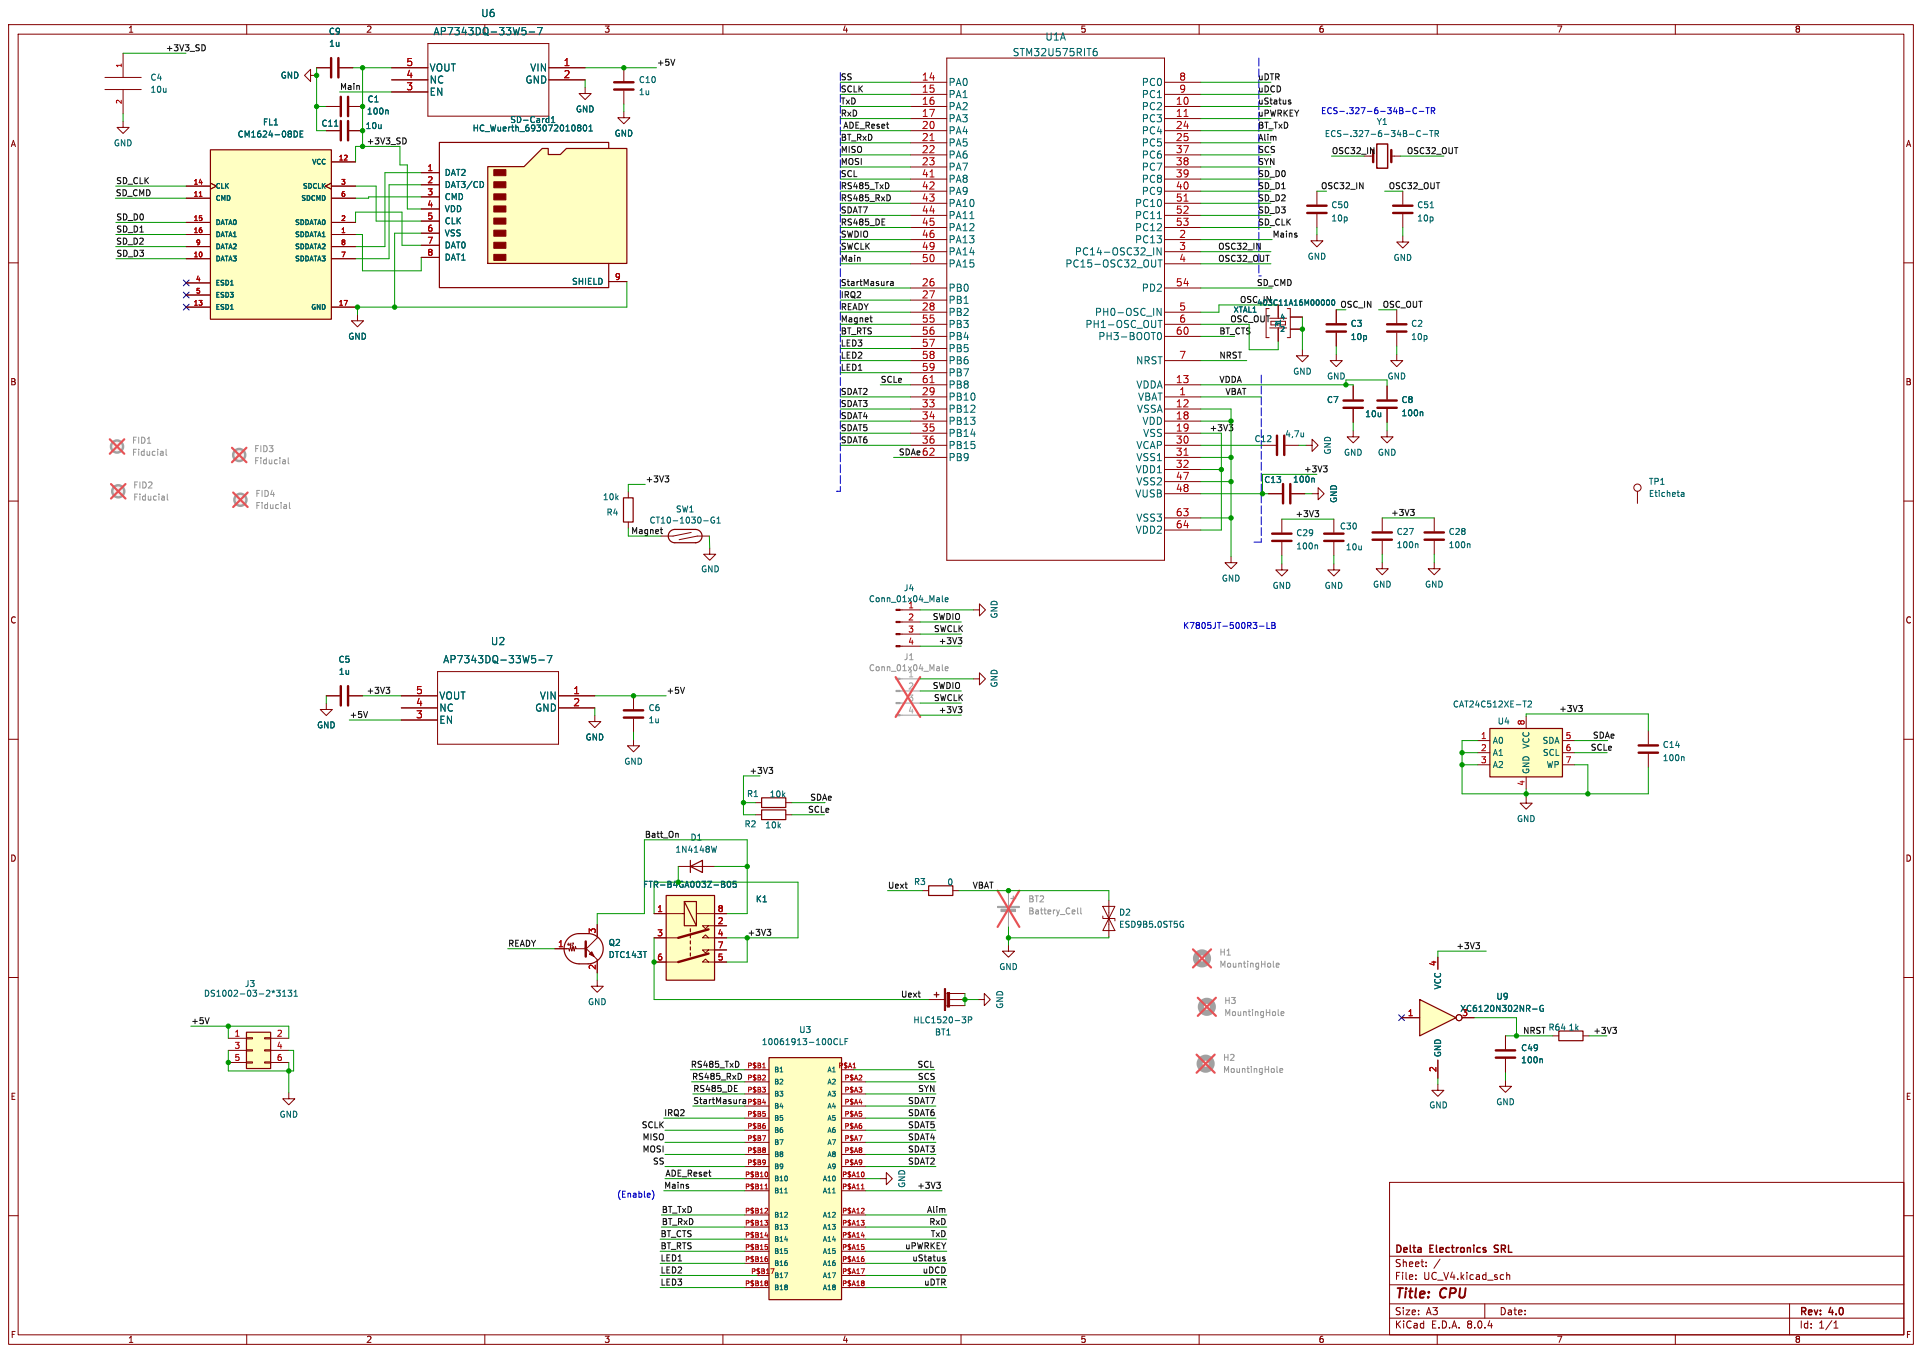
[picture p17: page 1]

4 SDA 5 SCL 6 WP 7 VCC

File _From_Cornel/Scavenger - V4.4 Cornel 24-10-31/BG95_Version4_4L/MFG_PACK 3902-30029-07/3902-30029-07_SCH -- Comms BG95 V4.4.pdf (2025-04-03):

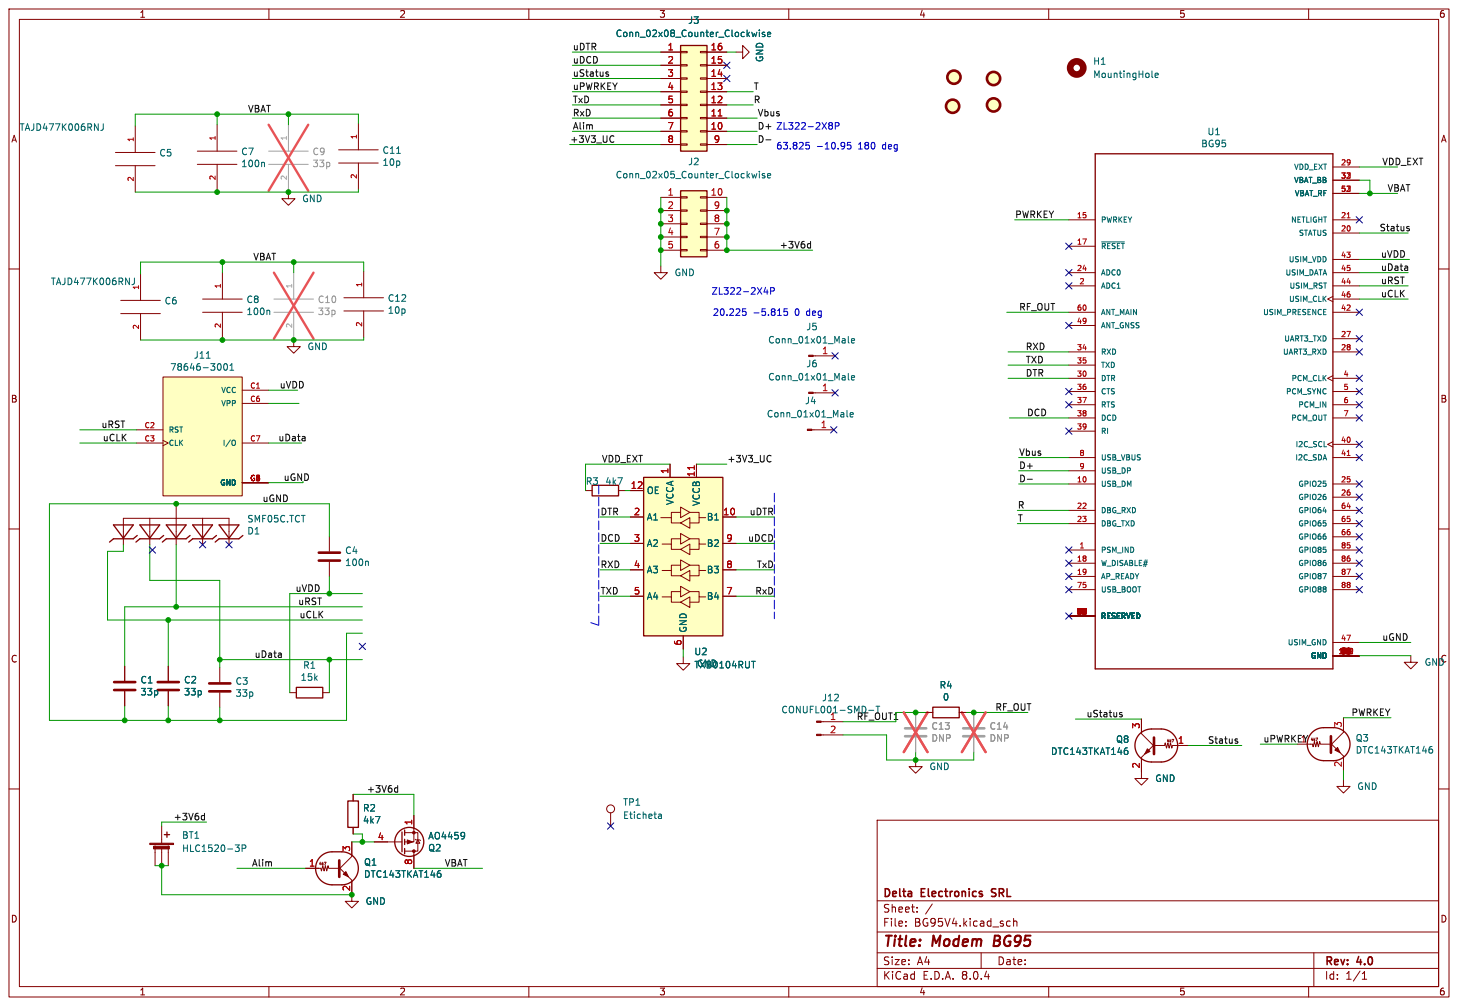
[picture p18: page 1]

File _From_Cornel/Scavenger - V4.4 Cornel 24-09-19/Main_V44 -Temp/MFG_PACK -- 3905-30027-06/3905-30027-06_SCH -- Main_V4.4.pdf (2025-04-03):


IRQ1 SS MOSI UT+US+

READY
IRQ2 SCLK
IRQ1 UR- UT- UR+ UT+

SCL US+ UR- US- UT+ UR+ VN

SDIx CS2 SCLKx SDO2 UT+ SDAT2 SCS

UR- UT+ UT- US+ US- UR+ SCS

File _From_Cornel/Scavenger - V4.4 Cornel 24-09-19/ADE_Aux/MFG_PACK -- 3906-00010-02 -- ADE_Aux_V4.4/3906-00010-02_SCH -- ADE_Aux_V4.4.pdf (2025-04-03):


DVDDOUT UR- US- UR+

Id: 1/1 Title: ADE Interface

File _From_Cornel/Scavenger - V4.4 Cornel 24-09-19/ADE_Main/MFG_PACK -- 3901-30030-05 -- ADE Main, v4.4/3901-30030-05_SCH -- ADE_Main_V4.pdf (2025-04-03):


Id: 1/1 Title: ADE Interface

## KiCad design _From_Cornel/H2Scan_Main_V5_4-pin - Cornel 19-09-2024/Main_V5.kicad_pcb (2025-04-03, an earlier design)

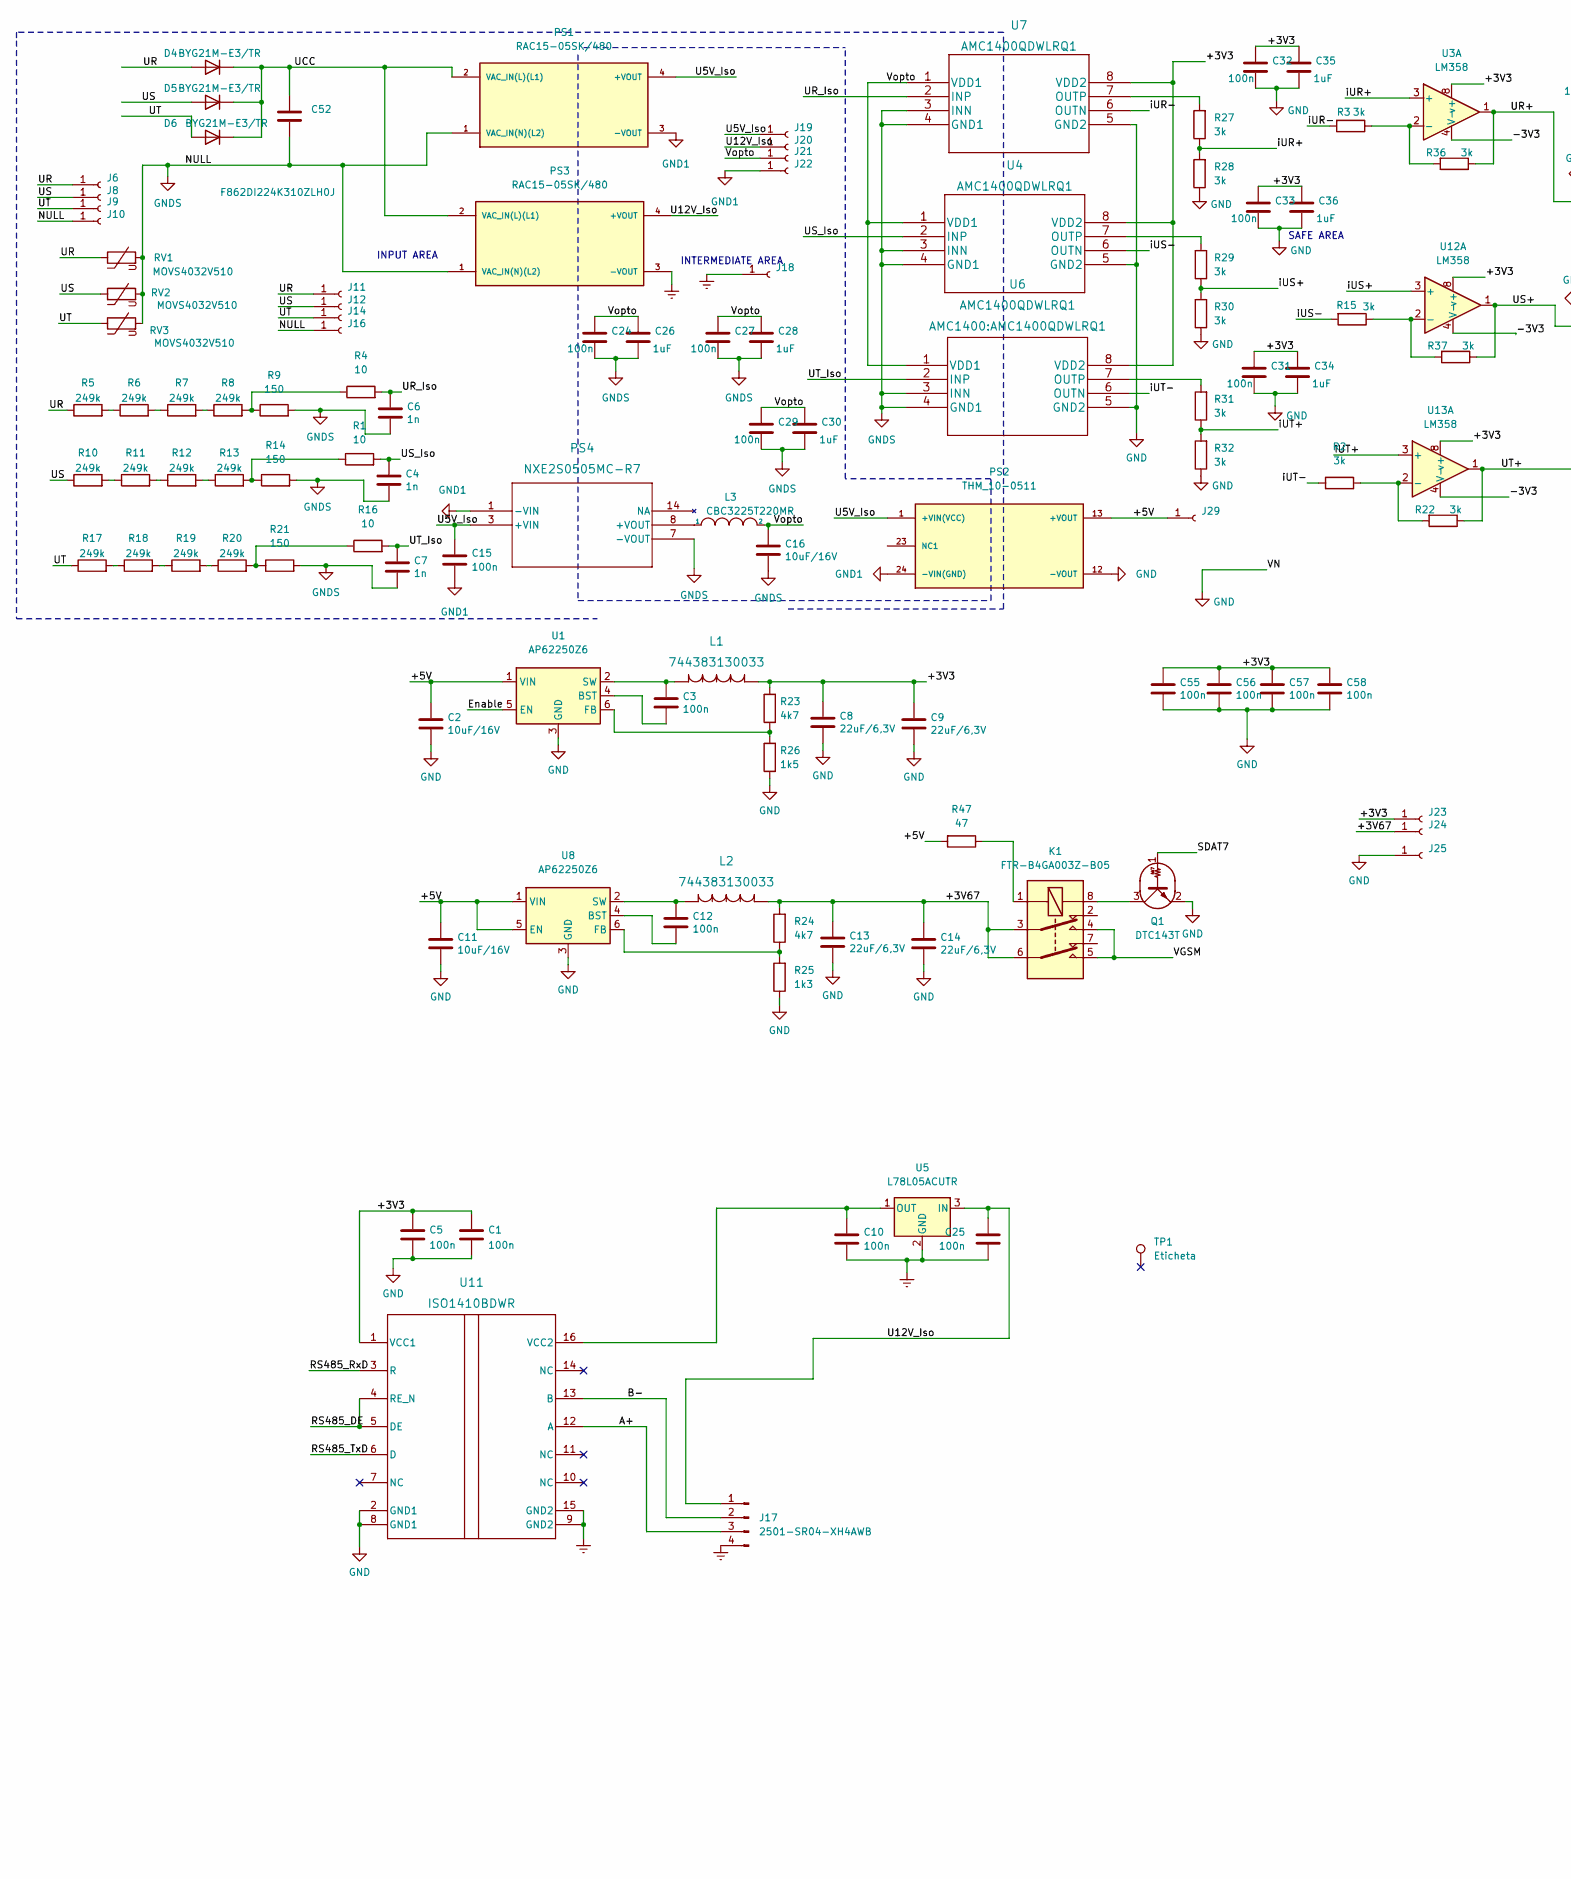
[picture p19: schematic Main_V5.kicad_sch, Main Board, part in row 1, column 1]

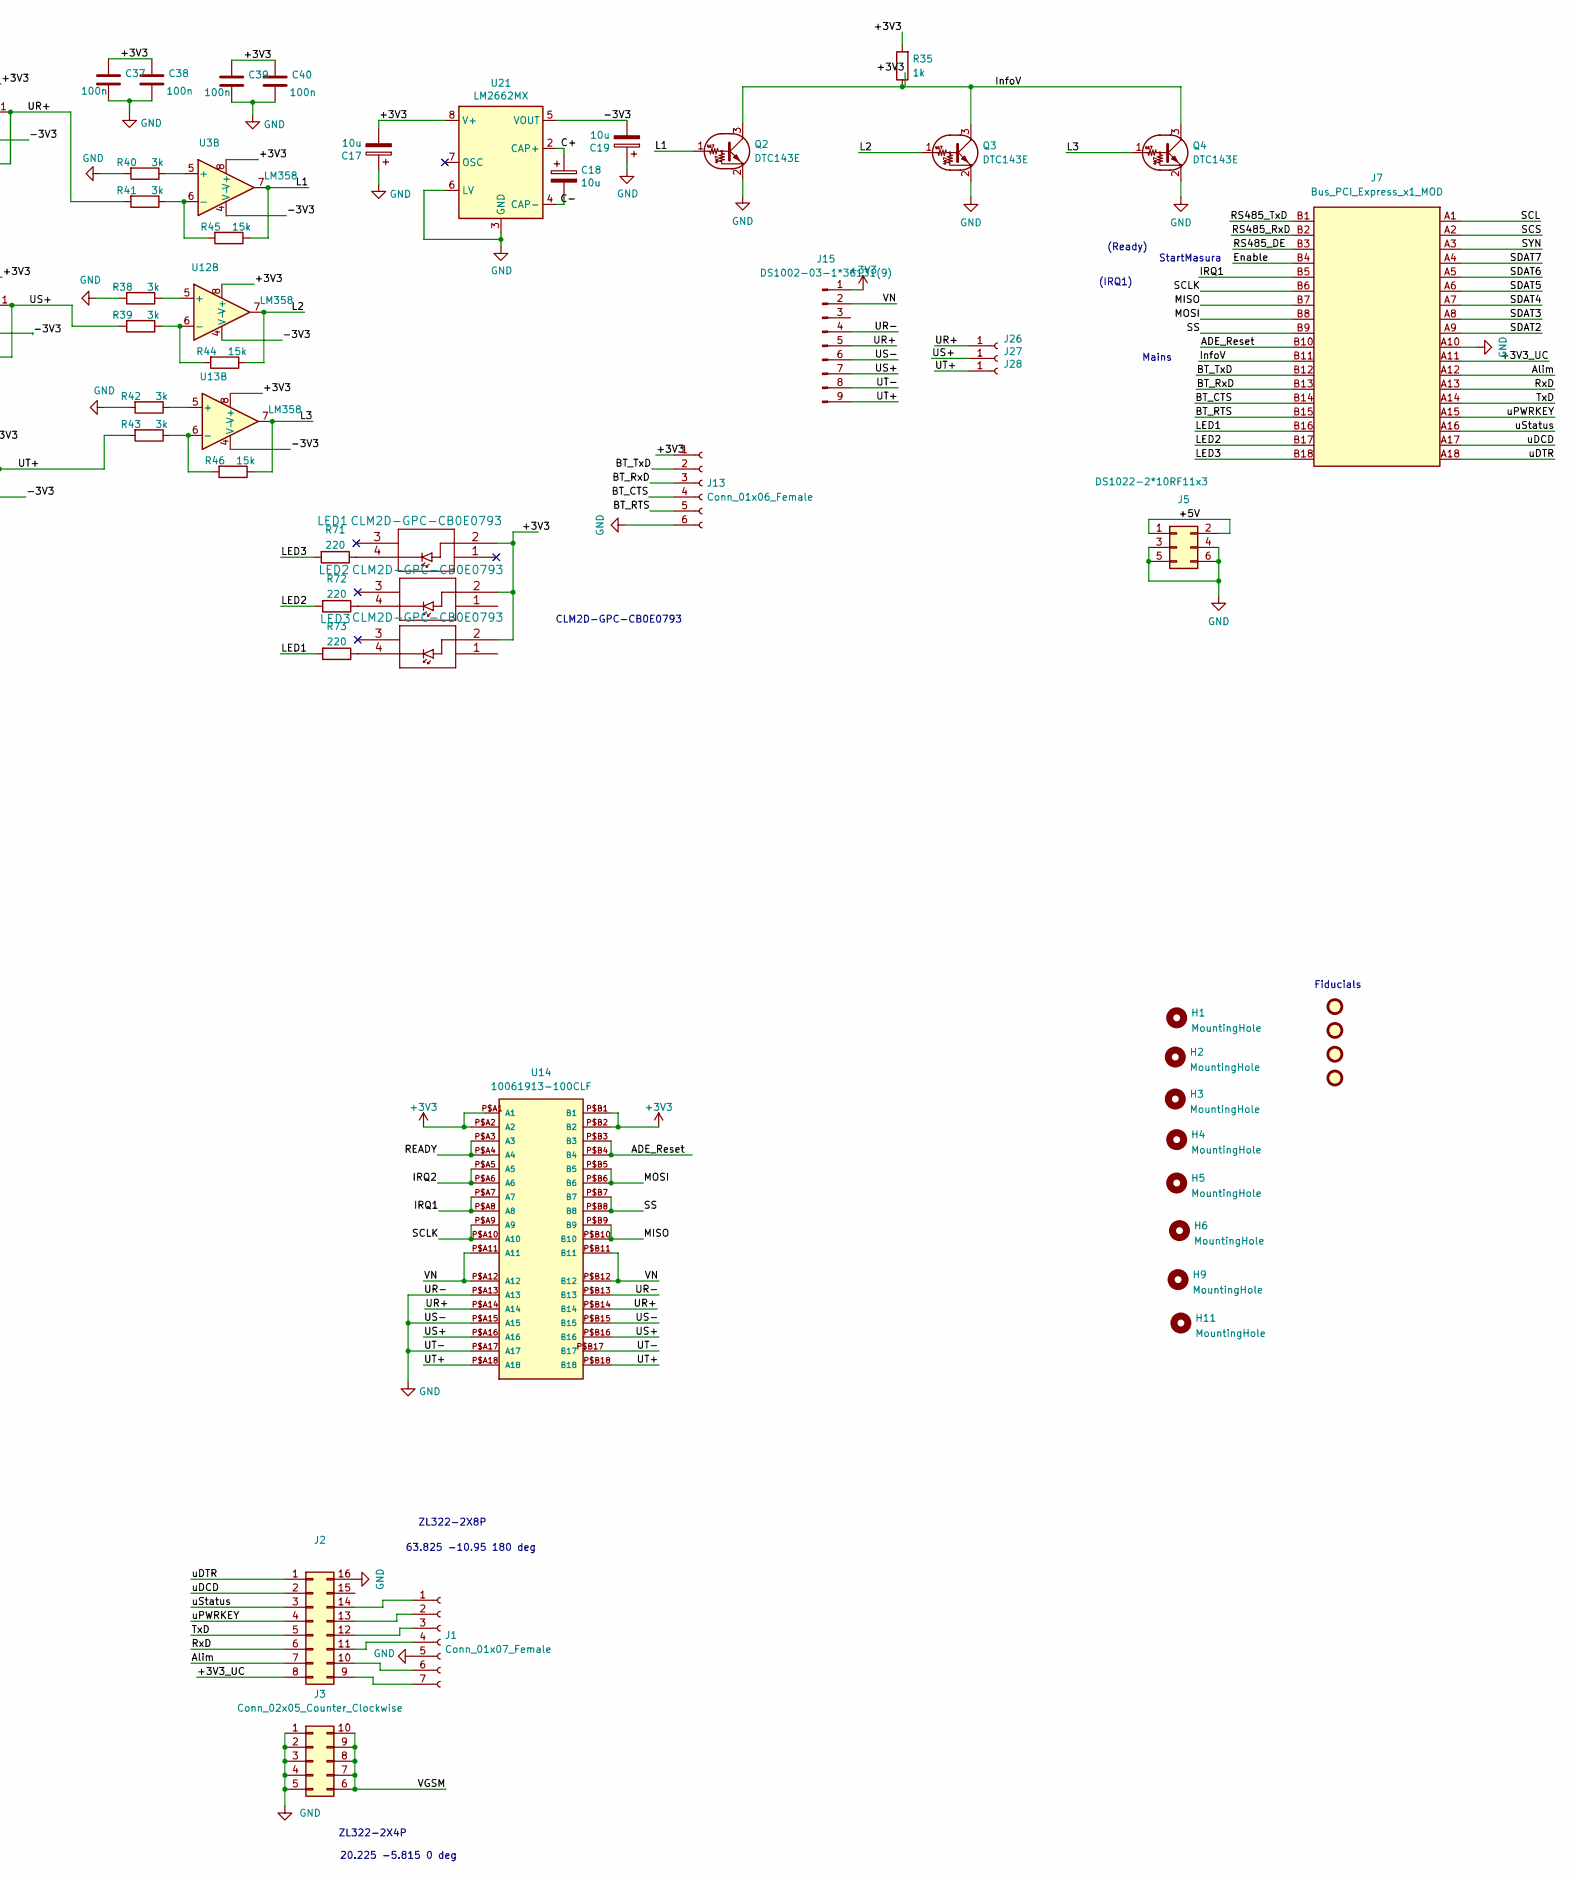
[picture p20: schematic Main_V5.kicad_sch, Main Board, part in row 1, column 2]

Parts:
C1, C3, C5, C10, C12, C15, C24, C25, C27, C29, C31, C32, C33, C37, C38, C39, C40, C55, C56, C57, C58: 100n; C_0603_1608Metric
C2, C11, C16: 10uF/16V; C_1206_3216Metric
C4, C6, C7: 1n; C_0603_1608Metric
C8, C9, C13, C14: 22uF/6,3V; C_1206_3216Metric
C17, C18, C19: 10u; C_1206_3216Metric
C26, C28, C30, C34, C35, C36: 1uF; C_0603_1608Metric
C52: F862DI224K310ZLH0J; C_Rect_L24.0mm_W7.0mm_P22.50mm_MKT
D4, D5, D6: BYG21M-E3/TR; D_SMA
FID1, FID2, FID3, FID4: Fiducial; Fiducial_1mm_Mask2mm
H1, H2, H3, H4, H5, H6, H9, H11: MountingHole; MountingHole_3.2mm_M3
J1: Conn_01x07_Female; PinSocket_1x07_P2.54mm_Vertical
J2: Conn_02x08_Counter_Clockwise; PinSocket_2x08_P2.54mm_Vertical_SMD_MOD
J3: Conn_02x05_Counter_Clockwise; PinSocket_2x05_P2.54mm_Vertical_SMD
J5: DS1022-2*10RF11x3; PinHeader_2x03_P2.54mm_Horizontal
J6: Conn_01x01_Female; DELTA_SolderWire-1.5sqmm_1x01_D1.7mm_OD3.9mm
J7: Bus_PCI_Express_x1_MOD; BUS_PCIexpress_x1
J8, J9, J10: Conn_01x01_Female; DELTA_R_SolderWire-1.5sqmm_1x01_D1.7mm_OD3.9mm
J11, J12, J14, J16, J18, J19, J20, J21, J22, J23, J24, J25, J26, J27, J28, J29: Conn_01x01_Female; TestPoint_Pad_2.5x2.5mm_Delta
J13: Conn_01x06_Female; PinSocket_1x06_P2.54mm_Vertical
J15: DS1002-03-1*36131(9); PinSocket_1x09_P2.54mm_Vertical
J17: 2501-SR04-XH4AWB; A2501-SR04-XH4AWB
K1: FTR-B4GA003Z-B05; Relay_Fujitsu_FTR-B4GA003
L1, L2: 744383130033
L3: CBC3225T220MR; L_1206_3216Metric
LED1, LED2, LED3: CLM2D-GPC-CB0E0793
PS1, PS3: RAC15-05SK/480; CONV_RAC15-12SK_480; PARTREV 0/2022
PS2: THM_10-0511; CONV_THM_10-0511; PARTREV Jan 06, 2021
PS4: NXE2S0505MC-R7; NXE2_SINGLE_SURFACE_MUR
Q1: DTC143T; SOT-23
Q2, Q3, Q4: DTC143E; SOT-23
R1, R4, R16: 10; R_0603_1608Metric
R2, R3, R15, R22, R27, R28, R29, R30, R31, R32, R36, R37, R38, R39, R40, R41, R42, R43: 3k; R_0603_1608Metric
R5, R6, R7, R8, R10, R11, R12, R13, R17, R18, R19, R20: 249k; R_2512_6332Metric
R9, R14, R21: 150; R_0603_1608Metric
R23, R24: 4k7; R_0603_1608Metric
R25: 1k3; R_0603_1608Metric
R26: 1k5; R_0603_1608Metric
R35: 1k; R_0603_1608Metric
R44, R45, R46: 15k; R_0603_1608Metric
R47: 47; R_0603_1608Metric
R71, R72, R73: 220; R_0603_1608Metric
RV1, RV2, RV3: MOVS4032V510; MOVS4032V460
TP1: Eticheta
U1, U8: AP62250Z6; SOT-563
U3, U12, U13: LM358; SO-8_3.9x4.9mm_P1.27mm
U4, U6, U7: AMC1400QDWLRQ1
U5: L78L05ACUTR; SOT-89-3
U11: ISO1410BDWR; DW0016B_HV
U14: 10061913-100CLF; MPN 10061913-100CLF
U21: LM2662MX; SO-8_3.9x4.9mm_P1.27mm

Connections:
+3V3: C1.1, C5.1, C8.1, C9.1, C17.2, C31.1, C32.1, C33.1, C34.1, C35.1, C36.1, C37.1, C38.1, C39.1, C40.1, C55.1, C56.1, C57.1, C58.1, J13.1, J15.1, J23.1, L1.1, LED1.2, LED2.2, LED3.2, R23.2, R35.2, U3.8 (v+), U4.8 (VDD2), U6.8 (VDD2), U7.8 (VDD2), U11.1 (VCC1), U12.8 (v+), U13.8 (v+), U14.P$A1 (A1), U14.P$A2 (A2), U14.P$B1 (B1), U14.P$B2 (B2), U21.8 (V+)
/+3V3_UC: J2.8, J7.A11
/+3V67: C13.1, C14.1, J24.1, K1.3, K1.6, L2.1, R24.2
/+5V: C2.1, C11.1, J5.1, J5.2, J29.1, PS2.13 (+VOUT), R47.2, U1.1 (VIN), U8.1 (VIN), U8.5 (EN)
/-3V3: C19.2, U3.4 (V-), U12.4 (V-), U13.4 (V-), U21.5 (VOUT)
/A+: J17.3, U11.12 (A)
/ADE_Reset: J7.B10, U14.P$B3 (B3), U14.P$B4 (B4)
/Alim: J2.7, J7.A12
/B-: J17.2, U11.13 (B)
/BT_CTS: J7.B14, J13.4
/BT_RTS: J7.B15, J13.5
/BT_RxD: J7.B13, J13.3
/BT_TxD: J7.B12, J13.2
/C+: C18.1, U21.2 (CAP+)
/C-: C18.2, U21.4 (CAP-)
/Enable: J7.B4, U1.5 (EN)
/IRQ1: J7.B5, U14.P$A7 (A7), U14.P$A8 (A8)
/IRQ2: U14.P$A5 (A5), U14.P$A6 (A6)
/InfoV: J7.B11, Q2.3 (C), Q3.3 (C), Q4.3 (C), R35.1
/L1: Q2.1 (B), R45.1, U3.7
/L2: Q3.1 (B), R44.1, U12.7
/L3: Q4.1 (B), R46.1, U13.7
/LED1: J7.B16, R73.2
/LED2: J7.B17, R72.2
/LED3: J7.B18, R71.2
/MISO: J7.B7, U14.P$B9 (B9), U14.P$B10 (B10)
/MOSI: J7.B8, U14.P$B5 (B5), U14.P$B6 (B6)
/READY: U14.P$A3 (A3), U14.P$A4 (A4)
/RS485_DE: J7.B3, U11.4 (RE_N), U11.5 (DE)
/RS485_RxD: J7.B2, U11.3 (R)
/RS485_TxD: J7.B1, U11.6 (D)
/RxD: J2.6, J7.A13
/SCL: J7.A1
/SCLK: J7.B6, U14.P$A9 (A9), U14.P$A10 (A10)
/SCS: J7.A2
/SDAT2: J7.A9
/SDAT3: J7.A8
/SDAT4: J7.A7
/SDAT5: J7.A6
/SDAT6: J7.A5
/SDAT7: J7.A4, Q1.1 (B)
/SS: J7.B9, U14.P$B7 (B7), U14.P$B8 (B8)
/SYN: J7.A3
/TxD: J2.5, J7.A14
/U5V_Iso: C15.1, J19.1, PS1.4 (+VOUT), PS2.1 (+VIN(VCC)), PS4.3 (+VIN)
/U12V_Iso: C25.1, J17.1, J20.1, PS3.4 (+VOUT), U5.3 (IN)
/UCC: C52.1, D4.1 (K), D5.1 (K), D6.1 (K), PS1.2 (VAC_IN(L)(L1)), PS3.2 (VAC_IN(L)(L1))
/UR: D4.2 (A), J6.1, J11.1, R5.1, RV1.1
/UR+: J15.5, J26.1, R36.1, R41.2, U3.1, U14.P$A14 (A14), U14.P$B14 (B14)
/UR_Iso: C6.1, R4.2, U7.2 (INP)
/US: D5.2 (A), J8.1, J12.1, R10.1, RV2.1
/US+: J15.7, J27.1, R37.1, R39.2, U12.1, U14.P$A16 (A16), U14.P$B16 (B16)
/US_Iso: C4.1, R1.2, U4.2 (INP)
/UT: D6.2 (A), J9.1, J14.1, R17.1, RV3.1
/UT+: J15.9, J28.1, R22.1, R43.2, U13.1, U14.P$A18 (A18), U14.P$B18 (B18)
/UT_Iso: C7.1, R16.2, U6.2 (INP)
/VGSM: J3.6, J3.7, J3.8, J3.9, J3.10, K1.4, K1.5
/Vopto: C16.1, C24.1, C26.1, C27.1, C28.1, C29.1, C30.1, J21.1, L3.2, U4.1 (VDD1), U6.1 (VDD1), U7.1 (VDD1)
/iUR+: R27.1, R28.2, U3.3 (+)
/iUR-: R3.2, U7.6 (OUTN)
/iUS+: R29.1, R30.2, U12.3 (+)
/iUS-: R15.2, U4.6 (OUTN)
/iUT+: R31.1, R32.2, U13.3 (+)
/iUT-: R2.2, U6.6 (OUTN)
/uDCD: J2.2, J7.A17
/uDTR: J2.1, J7.A18
/uPWRKEY: J2.4, J7.A15
/uStatus: J2.3, J7.A16
Earth: C10.2, C25.2, J17.4, J18.1, PS3.3 (-VOUT), U5.2 (GND), U11.9 (GND2), U11.15 (GND2)
GND: C1.2, C2.2, C5.2, C8.2, C9.2, C11.2, C13.2, C14.2, C17.1, C19.1, C31.2, C32.2, C33.2, C34.2, C35.2, C36.2, C37.2, C38.2, C39.2, C40.2, C55.2, C56.2, C57.2, C58.2, J1.5, J2.16, J3.1, J3.2, J3.3, J3.4, J3.5, J5.3, J5.4, J5.5, J5.6, J7.A10, J13.6, J15.2, J15.4, J15.6, J15.8, J25.1, PS2.12 (-VOUT), Q1.2 (E), Q2.2 (E), Q3.2 (E), Q4.2 (E), R25.1, R26.1, R28.1, R30.1, R32.1, R38.2, R40.2, R42.2, U1.3 (GND), U4.5 (GND2), U6.5 (GND2), U7.5 (GND2), U8.3 (GND), U11.2 (GND1), U11.8 (GND1), U14.P$A11 (A11), U14.P$A12 (A12), U14.P$A13 (A13), U14.P$A15 (A15), U14.P$A17 (A17), U14.P$B11 (B11), U14.P$B12 (B12), U14.P$B13 (B13), U14.P$B15 (B15), U14.P$B17 (B17), U21.3 (GND), U21.6 (LV)
GND1: C15.2, J22.1, PS1.3 (-VOUT), PS2.24 (-VIN(GND)), PS4.1 (-VIN)
GNDS: C4.2, C6.2, C7.2, C16.2, C24.2, C26.2, C27.2, C28.2, C29.2, C30.2, C52.2, J10.1, J16.1, PS1.1 (VAC_IN(N)(L2)), PS3.1 (VAC_IN(N)(L2)), PS4.7 (-VOUT), R9.2, R14.2, R21.2, RV1.2, RV2.2, RV3.2, U4.3 (INN), U4.4 (GND1), U6.3 (INN), U6.4 (GND1), U7.3 (INN), U7.4 (GND1)
unnamed: J1.1, J2.14
unnamed: J1.2, J2.13
unnamed: J1.3, J2.12
unnamed: J1.4, J2.11
unnamed: J1.6, J2.10
unnamed: J1.7, J2.9
unnamed: K1.1, R47.1
unnamed: LED1.4, R71.1
unnamed: LED2.4, R72.1
unnamed: LED3.4, R73.1
unnamed: L3.1, PS4.8 (+VOUT)
unnamed: K1.8, Q1.3 (C)
unnamed: R1.1, R13.2, R14.1
unnamed: R4.1, R8.2, R9.1
unnamed: R5.2, R6.1
unnamed: R6.2, R7.1
unnamed: R7.2, R8.1
unnamed: R10.2, R11.1
unnamed: R11.2, R12.1
unnamed: R12.2, R13.1
unnamed: R16.1, R20.2, R21.1
unnamed: R17.2, R18.1
unnamed: R18.2, R19.1
unnamed: R19.2, R20.1
unnamed: C3.2, U1.4 (BST)
unnamed: R23.1, R26.2, U1.6 (FB)
unnamed: C3.1, L1.2, U1.2 (SW)
unnamed: R3.1, R36.2, U3.2 (-)
unnamed: R40.1, U3.5 (+)
unnamed: R41.1, R45.2, U3.6 (-)
unnamed: R29.2, U4.7 (OUTP)
unnamed: R31.2, U6.7 (OUTP)
unnamed: R27.2, U7.7 (OUTP)
unnamed: C12.2, U8.4 (BST)
unnamed: R24.1, R25.2, U8.6 (FB)
unnamed: C12.1, L2.2, U8.2 (SW)
unnamed: C10.1, U5.1 (OUT), U11.16 (VCC2)
unnamed: R15.1, R37.2, U12.2 (-)
unnamed: R38.1, U12.5 (+)
unnamed: R39.1, R44.2, U12.6 (-)
unnamed: R2.1, R22.2, U13.2 (-)
unnamed: R42.1, U13.5 (+)
unnamed: R43.1, R46.2, U13.6 (-)

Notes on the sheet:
ZL322-2X4P
ZL322-2X8P
20.225 -5.815 0 deg
(Ready)
Fiducials
Mains
(IRQ1)
CLM2D-GPC-CB0E0793
StartMasura
63.825 -10.95 180 deg
SAFE AREA
INPUT AREA
INTERMEDIATE AREA

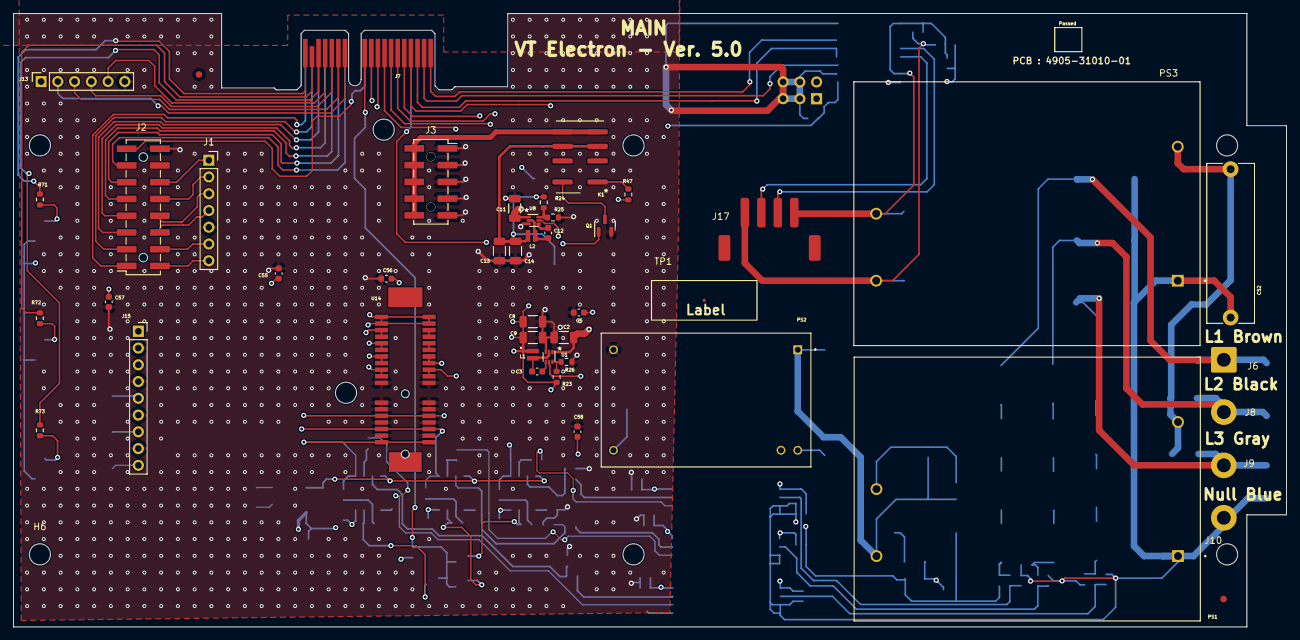
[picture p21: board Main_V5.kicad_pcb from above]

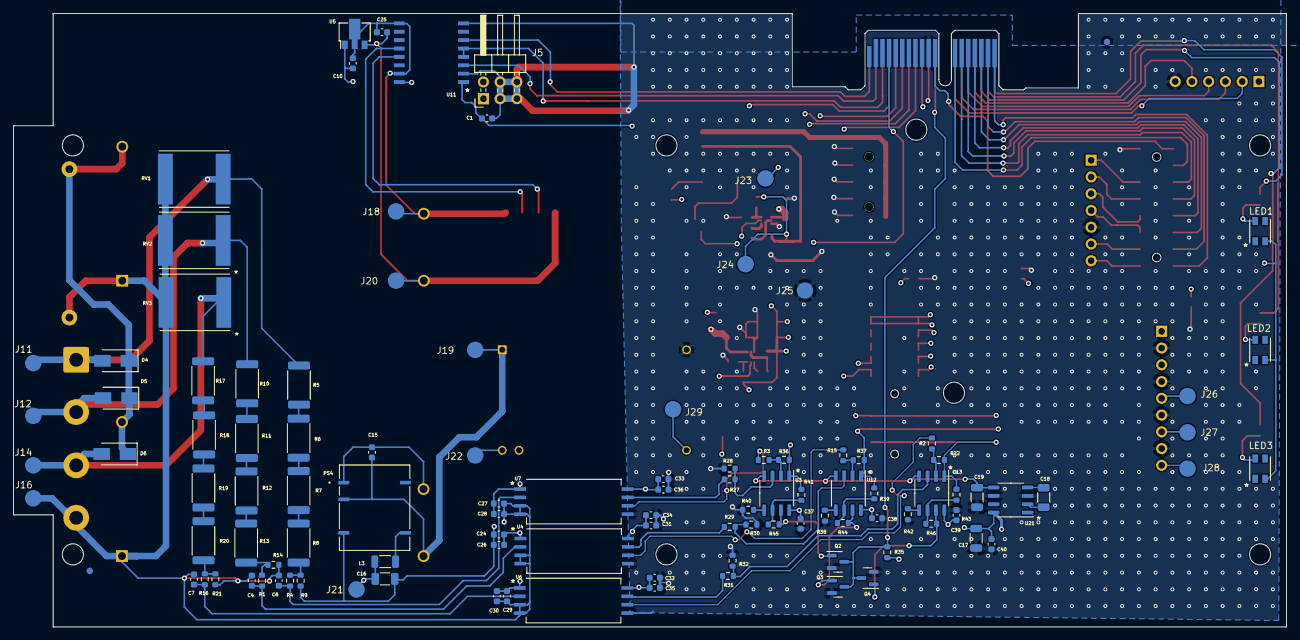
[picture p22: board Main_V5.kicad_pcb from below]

Board: 4 copper layers, 193.0 x 93.0 mm, 163 parts (109 on the bottom side), 107 nets.

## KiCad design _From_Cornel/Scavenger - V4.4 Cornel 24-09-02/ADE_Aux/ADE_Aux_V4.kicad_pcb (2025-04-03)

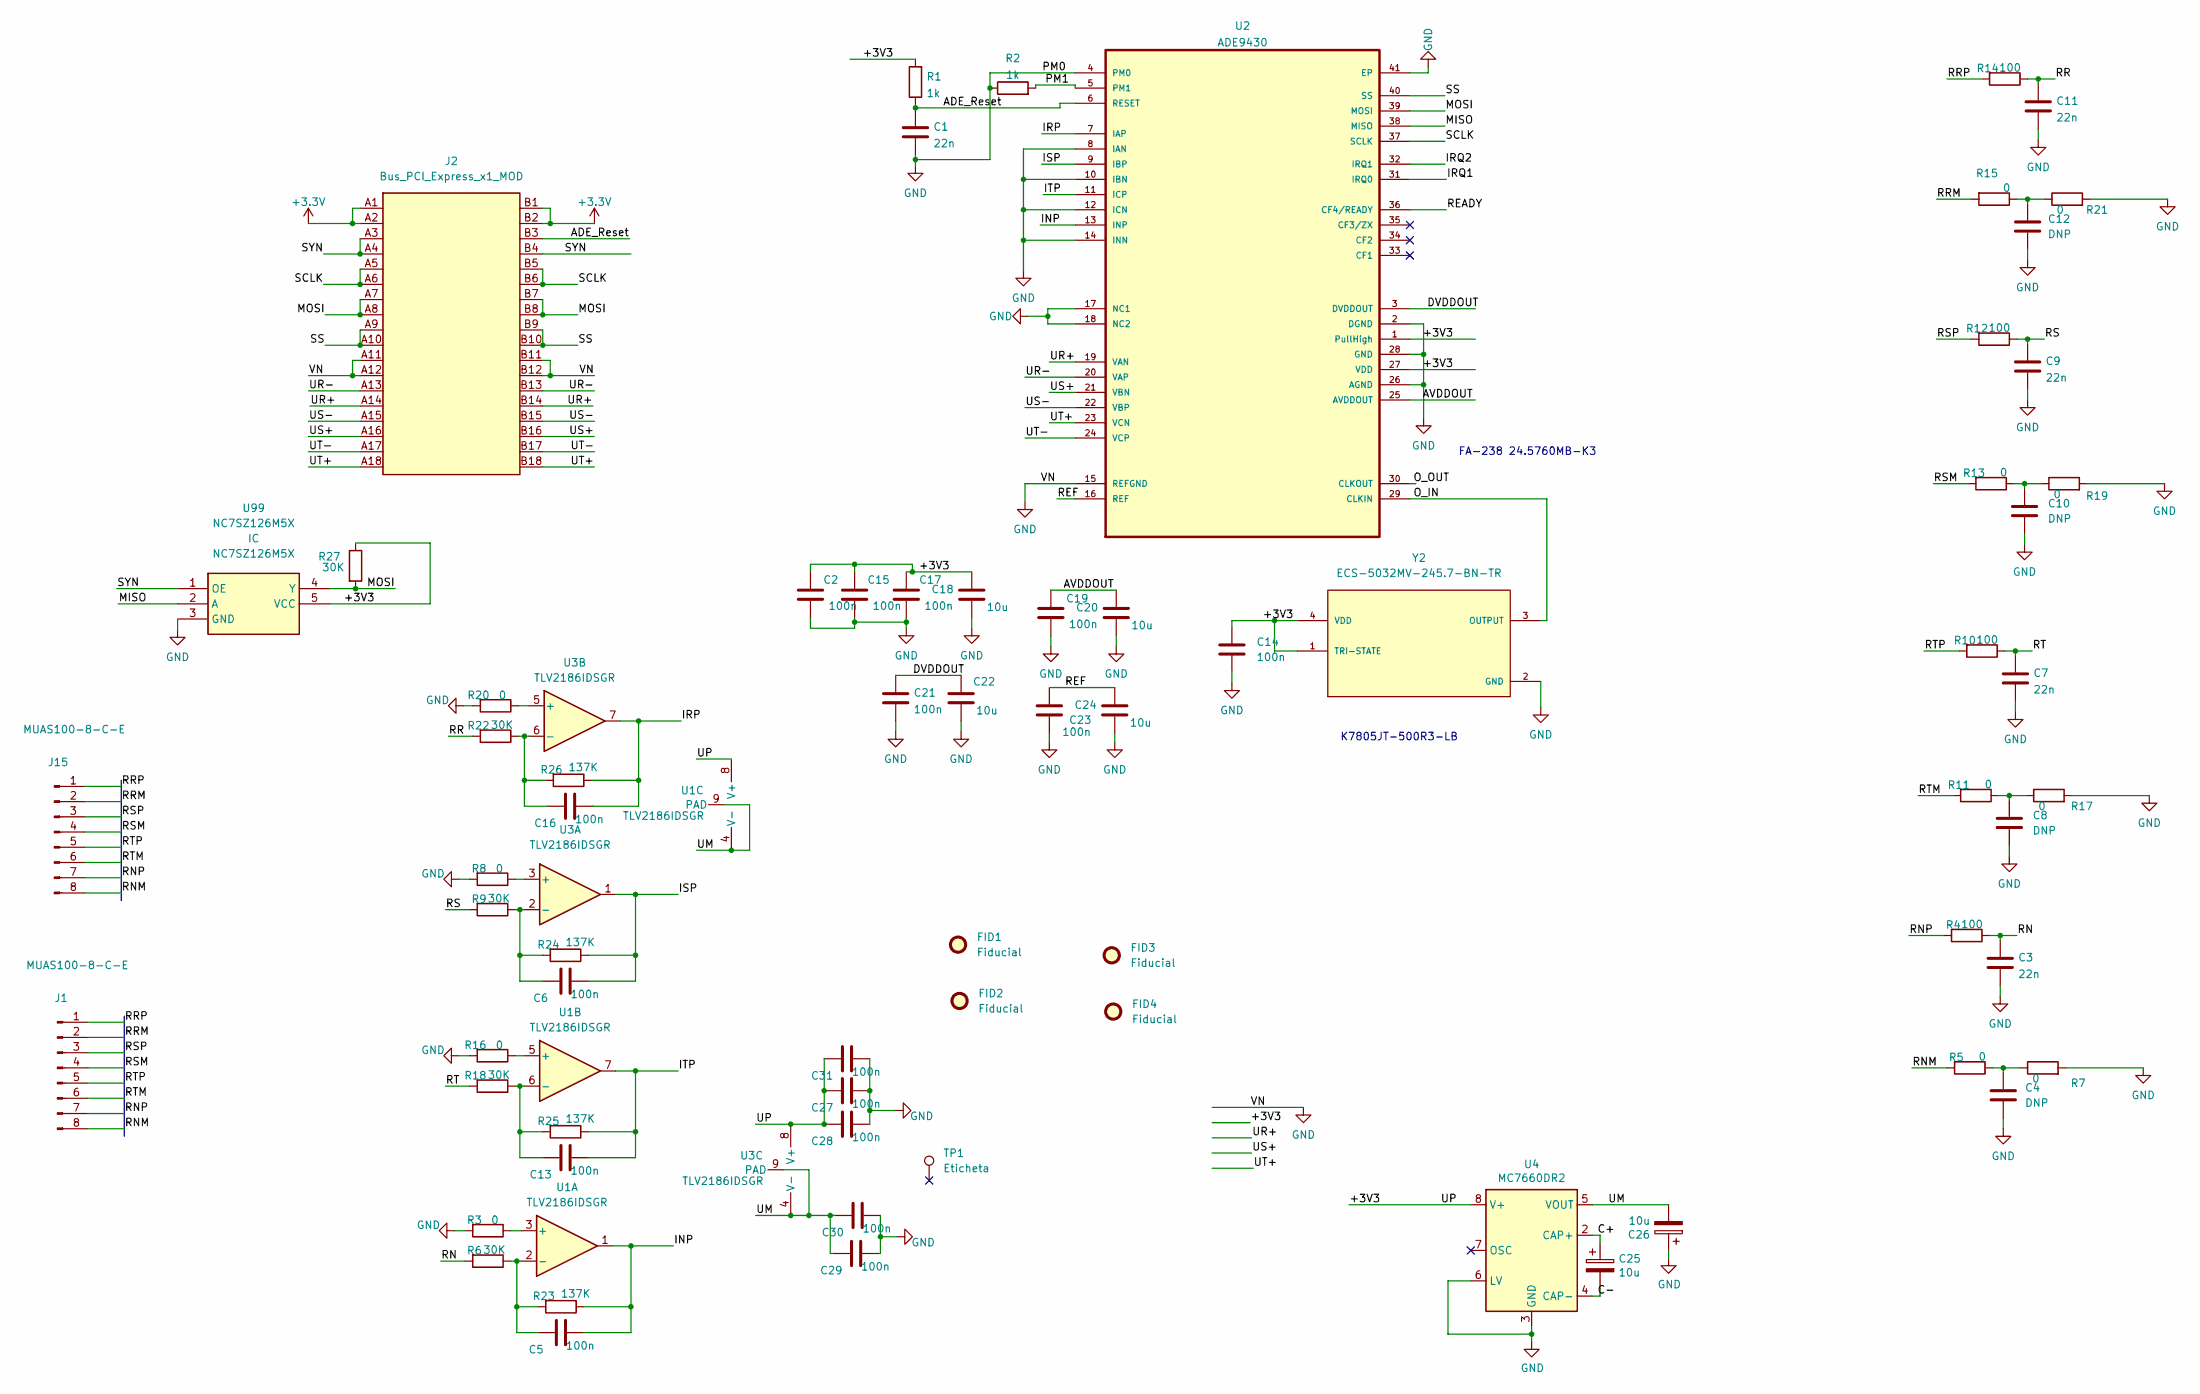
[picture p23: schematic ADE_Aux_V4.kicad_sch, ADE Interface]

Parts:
C1, C3, C7, C9, C11: 22n; C_0402_1005Metric
C2: 100n; C_0603_1608Metric
C4, C8, C10, C12: DNP; C_0402_1005Metric
C5, C6, C13, C14, C15, C16, C17, C19, C21, C23, C27, C28, C29, C30, C31: 100n; C_0402_1005Metric
C18, C20, C22, C24, C25, C26: 10u; C_1206_3216Metric
FID1, FID2, FID3, FID4: Fiducial; Fiducial_1mm_Mask2mm
J1: MUAS100-8-C-E; A2501-SR08-XH8AWB
J2: Bus_PCI_Express_x1_MOD; BUS_PCIexpress_x1
J15: MUAS100-8-C-E; PinHeader_1x08_P2.54mm_Vertical
R1, R2: 1k; R_0402_1005Metric
R3, R5, R7, R8, R11, R13, R15, R16, R17, R19, R20, R21: 0; R_0402_1005Metric
R4, R10, R12, R14: 100; R_0402_1005Metric
R6, R9, R18, R22, R27: 30K; R_0402_1005Metric
R23, R24, R25, R26: 137K; R_0402_1005Metric
TP1: Eticheta
U1, U3: TLV2186IDSGR; WSON-8-1EP_2x2mm_P0.5mm_EP0.9x1.6mm_ThermalVias
U2: ADE9430; MPN AD9115BCPZ
U4: MC7660DR2; SO-8_3.9x4.9mm_P1.27mm
U99: NC7SZ126M5X; Buffer3S; Manufacturer_Part_Number NC7SZ126M5X; Mouser Part Number 512-NC7SZ126M5X
Y2: ECS-5032MV-245.7-BN-TR; OSC_ECS-5032MV-245.7-BN-TR

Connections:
/ADE_Reset: C1.1, J2.B3, R1.1, U2.6 (RESET)
/AVDDOUT: C19.1, C20.1, U2.25 (AVDDOUT)
/C+: C25.1, U4.2 (CAP+)
/C-: C25.2, U4.4 (CAP-)
/DVDDOUT: C21.1, C22.1, U2.3 (DVDDOUT)
/INP: C5.1, R23.1, U1.1, U2.13 (INP)
/IRP: C16.1, R26.1, U2.7 (IAP), U3.7
/IRQ1: U2.31 (IRQ0)
/IRQ2: U2.32 (IRQ1)
/ISP: C6.1, R24.1, U2.9 (IBP), U3.1
/ITP: C13.1, R25.1, U1.7, U2.11 (ICP)
/MISO: U2.38 (MISO), U99.2 (A)
/MOSI: J2.A7, J2.A8, J2.B7, J2.B8, R27.2, U2.39 (MOSI), U99.4 (Y)
/O_IN: U2.29 (CLKIN), Y2.3 (OUTPUT)
/O_OUT: U2.30 (CLKOUT)
/PM1: R2.2, U2.5 (PM1)
/READY: U2.36 (CF4/READY)
/REF: C23.1, C24.1, U2.16 (REF)
/RN: C3.1, R4.1, R6.2
/RNM: J1.8, J15.8, R5.2
/RNP: J1.7, J15.7, R4.2
/RR: C11.1, R14.1, R22.2
/RRM: J1.2, J15.2, R15.2
/RRP: J1.1, J15.1, R14.2
/RS: C9.1, R9.2, R12.1
/RSM: J1.4, J15.4, R13.2
/RSP: J1.3, J15.3, R12.2
/RT: C7.1, R10.1, R18.2
/RTM: J1.6, J15.6, R11.2
/RTP: J1.5, J15.5, R10.2
/SCLK: J2.A5, J2.A6, J2.B5, J2.B6, U2.37 (SCLK)
/SS: J2.A9, J2.A10, J2.B9, J2.B10, U2.40 (SS)
/SYN: J2.A3, J2.A4, J2.B4, U99.1 (OE)
/UM: C26.2, C29.2, C30.2, U1.4 (V-), U1.9 (PAD), U3.4 (V-), U3.9 (PAD), U4.5 (VOUT)
/UR+: J2.A14, J2.B14, U2.19 (VAN)
/UR-: J2.A13, J2.B13, U2.20 (VAP)
/US+: J2.A16, J2.B16, U2.21 (VBN)
/US-: J2.A15, J2.B15, U2.22 (VBP)
/UT+: J2.A18, J2.B18, U2.23 (VCN)
/UT-: J2.A17, J2.B17, U2.24 (VCP)
GND: C1.2, C2.2, C3.2, C4.2, C7.2, C8.2, C9.2, C10.2, C11.2, C12.2, C14.2, C15.2, C17.2, C18.2, C19.2, C20.2, C21.2, C22.2, C23.2, C24.2, C26.1, C27.1, C28.1, C29.1, C30.1, C31.1, J2.A11, J2.A12, J2.B11, J2.B12, R2.1, R3.2, R7.2, R8.2, R16.2, R17.2, R19.2, R20.2, R21.2, U2.2 (DGND), U2.4 (PM0), U2.8 (IAN), U2.10 (IBN), U2.12 (ICN), U2.14 (INN), U2.15 (REFGND), U2.17 (NC1), U2.18 (NC2), U2.26 (AGND), U2.28 (GND), U2.41 (EP), U4.3 (GND), U4.6 (LV), U99.3 (GND), Y2.2 (GND)
unnamed: C4.1, R5.1, R7.1
unnamed: C5.2, R6.1, R23.2, U1.2 (-)
unnamed: C6.2, R9.1, R24.2, U3.2 (-)
unnamed: C8.1, R11.1, R17.1
unnamed: C10.1, R13.1, R19.1
unnamed: C12.1, R15.1, R21.1
unnamed: C13.2, R18.1, R25.2, U1.6 (-)
unnamed: C16.2, R22.1, R26.2, U3.6 (-)
unnamed: R3.1, U1.3 (+)
unnamed: R8.1, U3.3 (+)
unnamed: R16.1, U1.5 (+)
unnamed: R20.1, U3.5 (+)

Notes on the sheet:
FA-238 24.5760MB-K3
K7805JT-500R3-LB

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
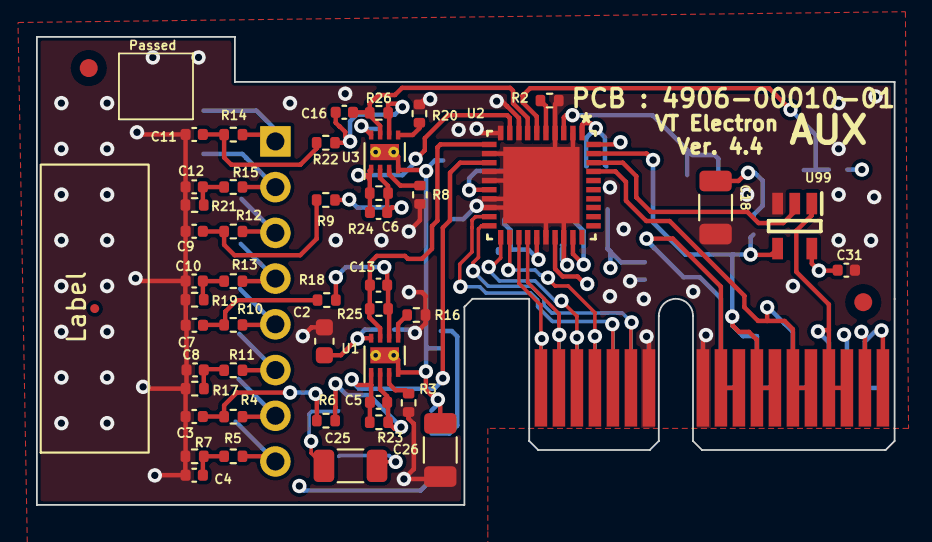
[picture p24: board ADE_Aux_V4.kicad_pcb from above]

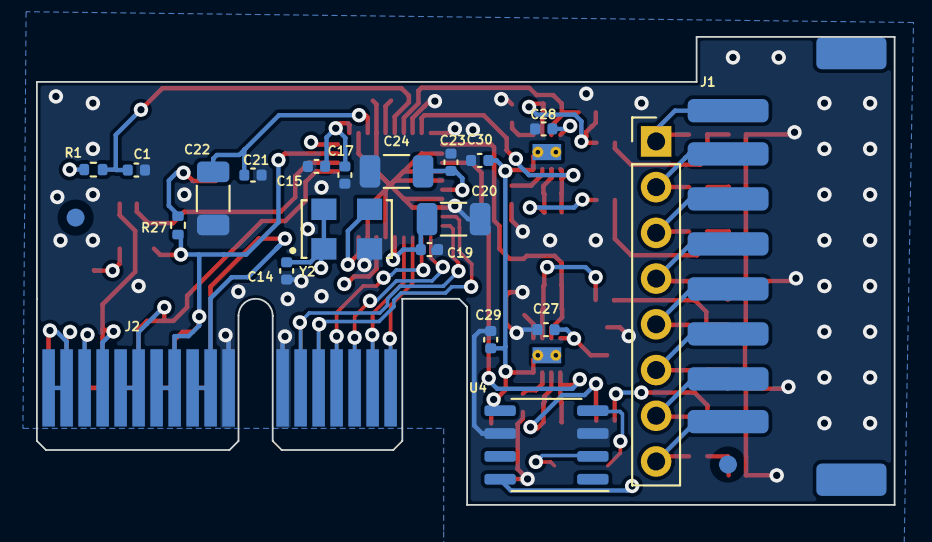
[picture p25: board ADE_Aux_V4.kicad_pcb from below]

Board: 4 copper layers, 47.6 x 26.0 mm, 72 parts (23 on the bottom side), 50 nets.

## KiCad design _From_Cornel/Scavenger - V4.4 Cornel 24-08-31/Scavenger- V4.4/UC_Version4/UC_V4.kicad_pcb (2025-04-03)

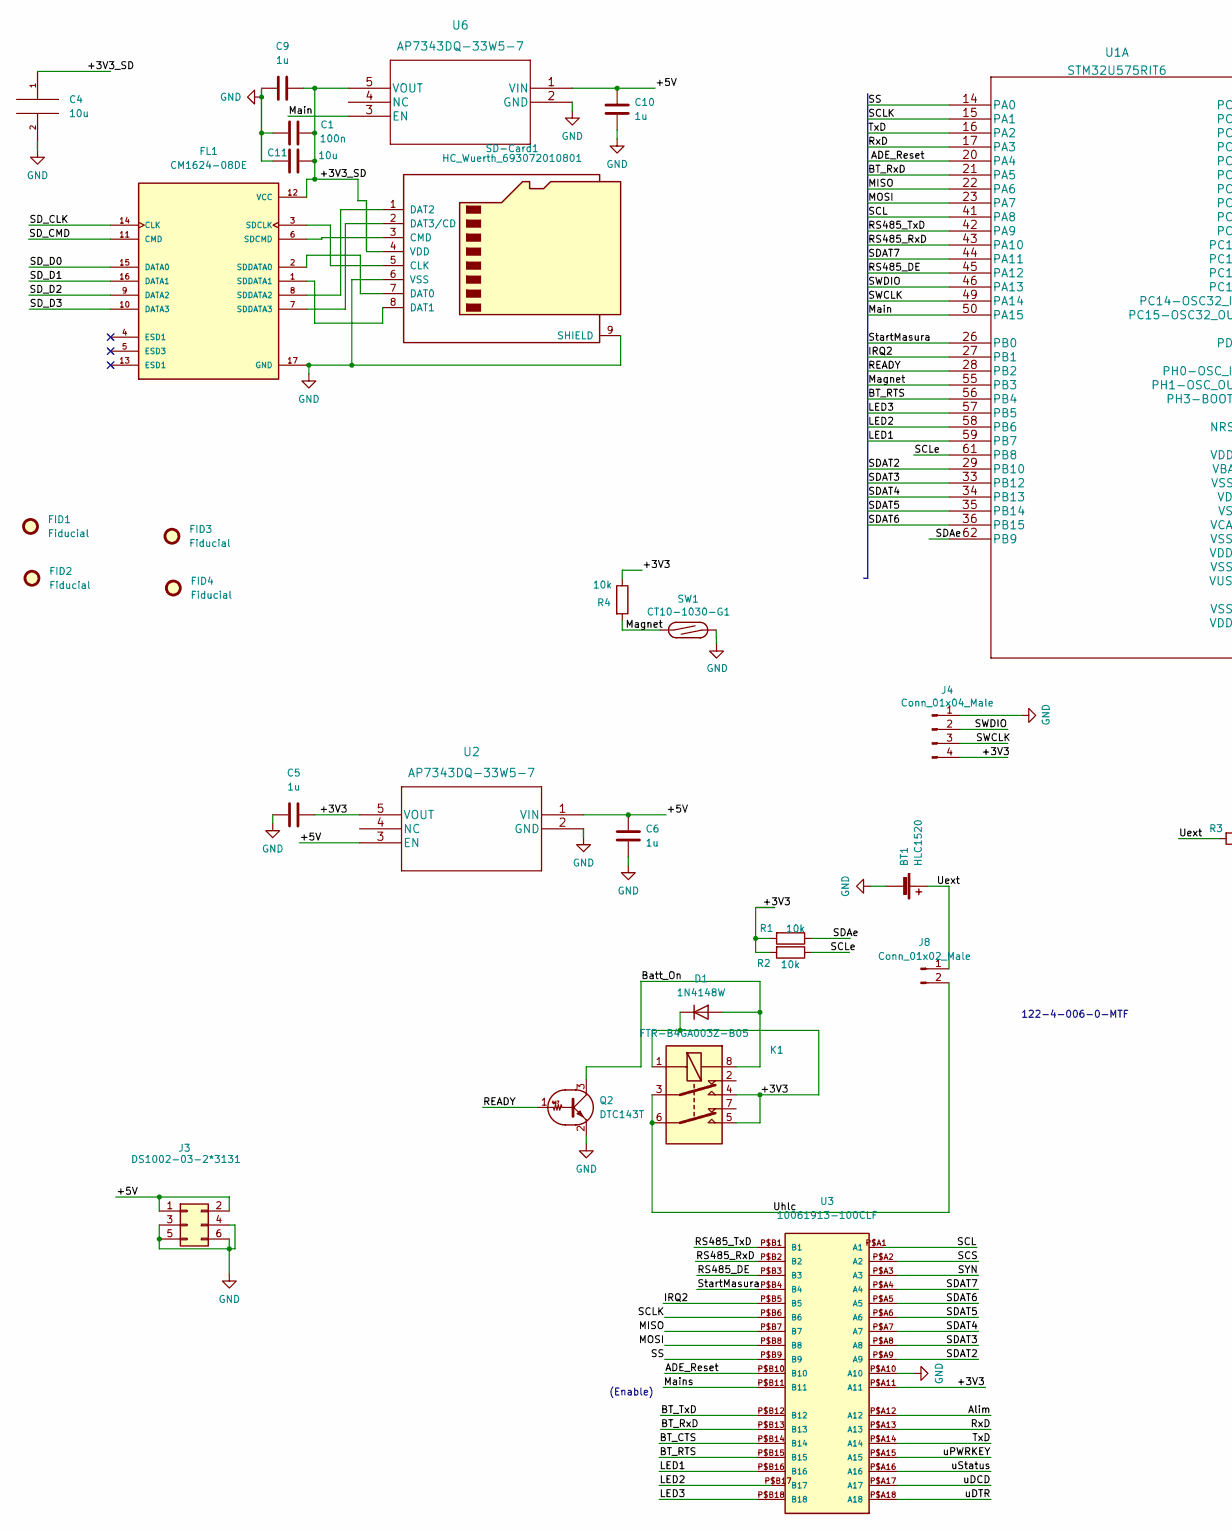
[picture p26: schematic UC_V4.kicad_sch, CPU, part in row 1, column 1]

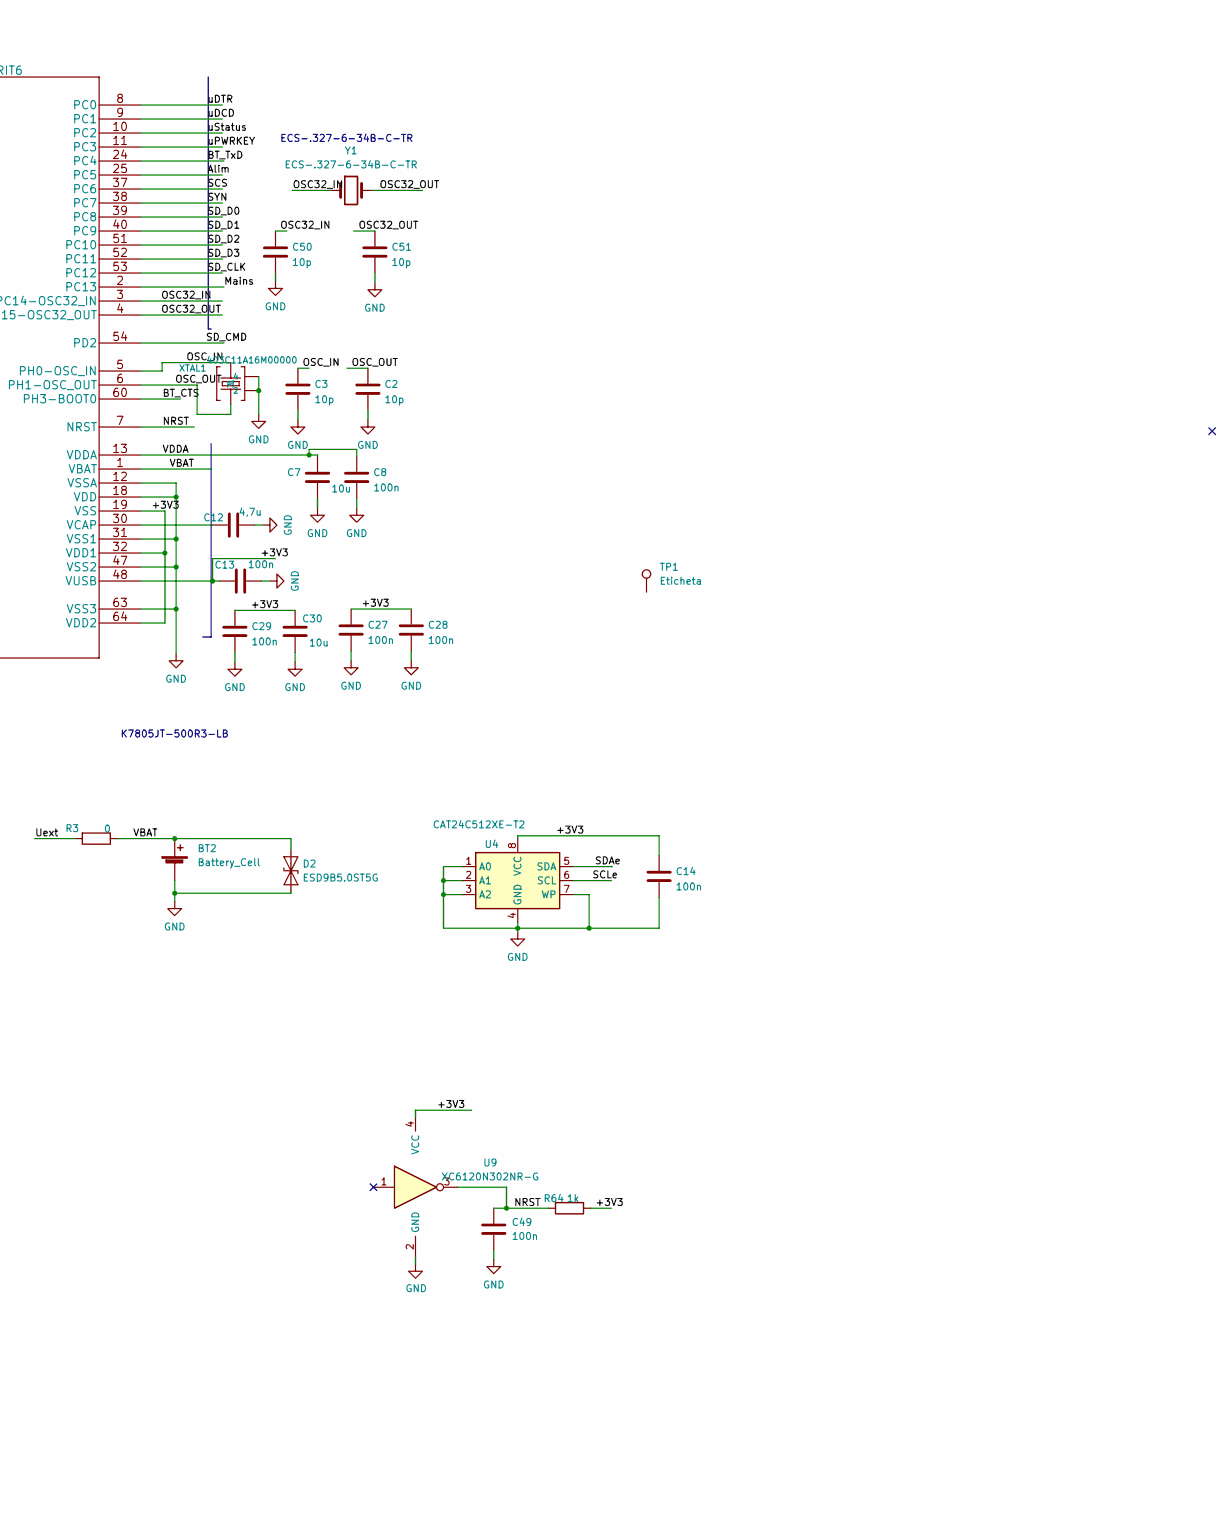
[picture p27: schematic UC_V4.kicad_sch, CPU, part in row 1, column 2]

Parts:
BT1: HLC1520
BT2: Battery_Cell; BatteryHolder_Keystone_3002_1x2032
C1, C8, C13, C14, C27, C28, C29, C49: 100n; C_0603_1608Metric
C2, C3, C50, C51: 10p; C_0603_1608Metric
C4, C7, C11, C30: 10u; C_1206_3216Metric
C5, C6, C9, C10: 1u; C_0603_1608Metric
C12: 4,7u; C_1206_3216Metric
D1: 1N4148W; D_SOD-123
D2: ESD9B5.0ST5G; SOD-923_ONS
FID1, FID2, FID3, FID4: Fiducial; Fiducial_1mm_Mask2mm
FL1: CM1624-08DE; FIL_CM1624; PARTREV 4
J3: DS1002-03-2*3131; PinSocket_2x03_P2.54mm_Vertical
J4: Conn_01x04_Male; PinHeader_1x04_P2.54mm_Vertical
J8: Conn_01x02_Male; PinHeader_1x02_P2.54mm_Vertical
K1: FTR-B4GA003Z-B05; Relay_Fujitsu_FTR-B4GA003
Q2: DTC143T; SOT-23
R1, R2, R4: 10k; R_0603_1608Metric
R3: 0; R_0603_1608Metric
R64: 1k; R_0603_1608Metric
SD-Card1: HC_Wuerth_693072010801; microSD_HC_Wuerth_693072010801
SW1: CT10-1030-G1; SW_SPST_REED_CT10-XXXX-G1
TP1: Eticheta
U1: STM32U575RIT6; LQFP-64_10x10mm_P0.5mm
U2, U6: AP7343DQ-33W5-7; AP3012KTR-G1
U3: 10061913-100CLF; MPN 10061913-100CLF
U4: CAT24C512XE-T2; SO-8_3.9x4.9mm_P1.27mm
U9: XC6120N302NR-G; SC-82AA
XTAL1: 403C11A16M00000; Crystal_SMD_SeikoEpson_TSX3225-4Pin_3.2x2.5mm
Y1: ECS-.327-6-34B-C-TR; Crystal_SMD_EuroQuartz_EQ161-2Pin_3.2x1.5mm

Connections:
/+3V3: C5.2, C13.1, C14.1, C27.1, C28.1, C29.1, C30.1, D1.1 (K), J4.4, K1.1, K1.4, K1.5, R1.2, R2.2, R4.1, R64.1, U1.19 (VSS), U1.32 (VDD1), U1.48 (VUSB), U1.64 (VDD2), U2.5 (VOUT), U3.P$A11 (A11), U4.8 (VCC), U9.4 (VCC)
/+3V3_SD: C1.2, C4.1, C9.2, C11.2, FL1.12 (VCC), SD-Card1.4 (VDD), U6.5 (VOUT)
/+5V: C6.1, C10.1, J3.1, J3.2, U2.1 (VIN), U2.3 (EN), U6.1 (VIN)
/ADE_Reset: U1.20 (PA4), U3.P$B10 (B10)
/Alim: U1.25 (PC5), U3.P$A12 (A12)
/BT_CTS: U1.60 (PH3-BOOT0), U3.P$B14 (B14)
/BT_RTS: U1.56 (PB4), U3.P$B15 (B15)
/BT_RxD: U1.21 (PA5), U3.P$B13 (B13)
/BT_TxD: U1.24 (PC4), U3.P$B12 (B12)
/Batt_On: D1.2 (A), K1.8, Q2.3 (C)
/IRQ2: U1.27 (PB1), U3.P$B5 (B5)
/LED1: U1.59 (PB7), U3.P$B16 (B16)
/LED2: U1.58 (PB6), U3.P$B17 (B17)
/LED3: U1.57 (PB5), U3.P$B18 (B18)
/MISO: U1.22 (PA6), U3.P$B7 (B7)
/MOSI: U1.23 (PA7), U3.P$B8 (B8)
/Magnet: R4.2, SW1.1, U1.55 (PB3)
/Main: U1.50 (PA15), U6.3 (EN)
/Mains: U1.2 (PC13), U3.P$B11 (B11)
/NRST: C49.1, R64.2, U1.7 (NRST), U9.3
/OSC32_IN: C50.1, U1.3 (PC14-OSC32_IN), Y1.1
/OSC32_OUT: C51.1, U1.4 (PC15-OSC32_OUT), Y1.2
/OSC_IN: C3.1, U1.5 (PH0-OSC_IN), XTAL1.3
/OSC_OUT: C2.1, U1.6 (PH1-OSC_OUT), XTAL1.1
/READY: Q2.1 (B), U1.28 (PB2)
/RS485_DE: U1.45 (PA12), U3.P$B3 (B3)
/RS485_RxD: U1.43 (PA10), U3.P$B2 (B2)
/RS485_TxD: U1.42 (PA9), U3.P$B1 (B1)
/RxD: U1.17 (PA3), U3.P$A13 (A13)
/SCL: U1.41 (PA8), U3.P$A1 (A1)
/SCLK: U1.15 (PA1), U3.P$B6 (B6)
/SCLe: R2.1, U1.61 (PB8), U4.6 (SCL)
/SCS: U1.37 (PC6), U3.P$A2 (A2)
/SDAT2: U1.29 (PB10), U3.P$A9 (A9)
/SDAT3: U1.33 (PB12), U3.P$A8 (A8)
/SDAT4: U1.34 (PB13), U3.P$A7 (A7)
/SDAT5: U1.35 (PB14), U3.P$A6 (A6)
/SDAT6: U1.36 (PB15), U3.P$A5 (A5)
/SDAT7: U1.44 (PA11), U3.P$A4 (A4)
/SDAe: R1.1, U1.62 (PB9), U4.5 (SDA)
/SD_CLK: FL1.14 (CLK), U1.53 (PC12)
/SD_CMD: FL1.11 (CMD), U1.54 (PD2)
/SD_D0: FL1.15 (DATA0), U1.39 (PC8)
/SD_D1: FL1.16 (DATA1), U1.40 (PC9)
/SD_D2: FL1.9 (DATA2), U1.51 (PC10)
/SD_D3: FL1.10 (DATA3), U1.52 (PC11)
/SS: U1.14 (PA0), U3.P$B9 (B9)
/SWCLK: J4.3, U1.49 (PA14)
/SWDIO: J4.2, U1.46 (PA13)
/SYN: U1.38 (PC7), U3.P$A3 (A3)
/StartMasura: U1.26 (PB0), U3.P$B4 (B4)
/TxD: U1.16 (PA2), U3.P$A14 (A14)
/Uext: BT1.1 (+), J8.1, R3.2
/Uhlc: J8.2, K1.3, K1.6
/VBAT: BT2.1 (+), D2.2 (A2), R3.1, U1.1 (VBAT)
/VDDA: C7.1, C8.1, U1.13 (VDDA)
/uDCD: U1.9 (PC1), U3.P$A17 (A17)
/uDTR: U1.8 (PC0), U3.P$A18 (A18)
/uPWRKEY: U1.11 (PC3), U3.P$A15 (A15)
/uStatus: U1.10 (PC2), U3.P$A16 (A16)
GND: BT1.2 (-), BT2.2 (-), C1.1, C2.2, C3.2, C4.2, C5.1, C6.2, C7.2, C8.2, C9.1, C10.2, C11.1, C12.2, C13.2, C14.2, C27.2, C28.2, C29.2, C30.2, C49.2, C50.2, C51.2, D2.1 (A1), FL1.17 (GND), J3.3, J3.4, J3.5, J3.6, J4.1, Q2.2 (E), SD-Card1.6 (VSS), SD-Card1.9 (SHIELD), SW1.2, U1.12 (VSSA), U1.18 (VDD), U1.31 (VSS1), U1.47 (VSS2), U1.63 (VSS3), U2.2 (GND), U3.P$A10 (A10), U4.1 (A0), U4.2 (A1), U4.3 (A2), U4.4 (GND), U4.7 (WP), U6.2 (GND), U9.2 (GND), XTAL1.2, XTAL1.4
unnamed: C12.1, U1.30 (VCAP)
unnamed: FL1.1 (SDDATA1), SD-Card1.8 (DAT1)
unnamed: FL1.2 (SDDATA0), SD-Card1.7 (DAT0)
unnamed: FL1.3 (SDCLK), SD-Card1.5 (CLK)
unnamed: FL1.6 (SDCMD), SD-Card1.3 (CMD)
unnamed: FL1.7 (SDDATA3), SD-Card1.2 (DAT3/CD)
unnamed: FL1.8 (SDDATA2), SD-Card1.1 (DAT2)

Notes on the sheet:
ECS-.327-6-34B-C-TR
K7805JT-500R3-LB
(Enable)
122-4-006-0-MTF

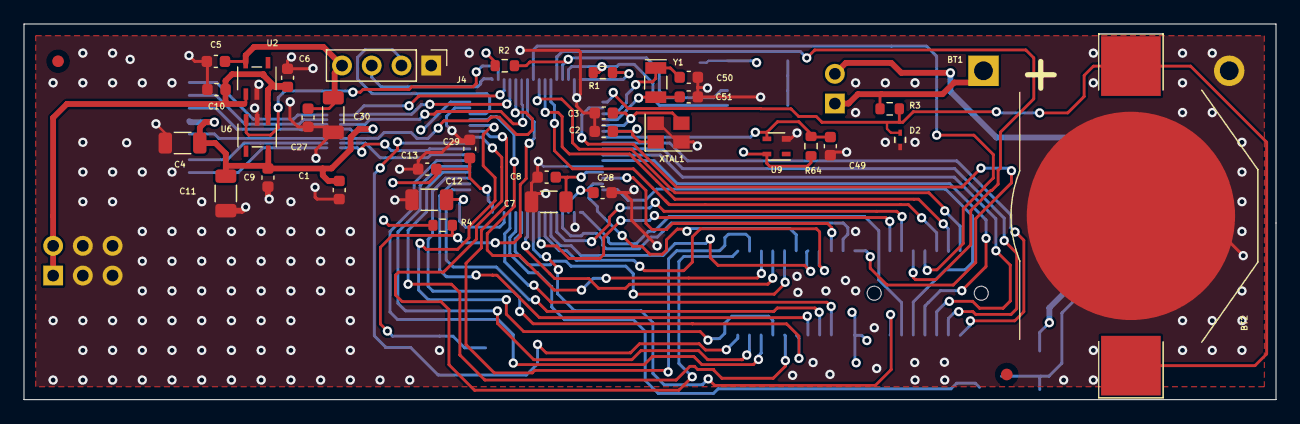
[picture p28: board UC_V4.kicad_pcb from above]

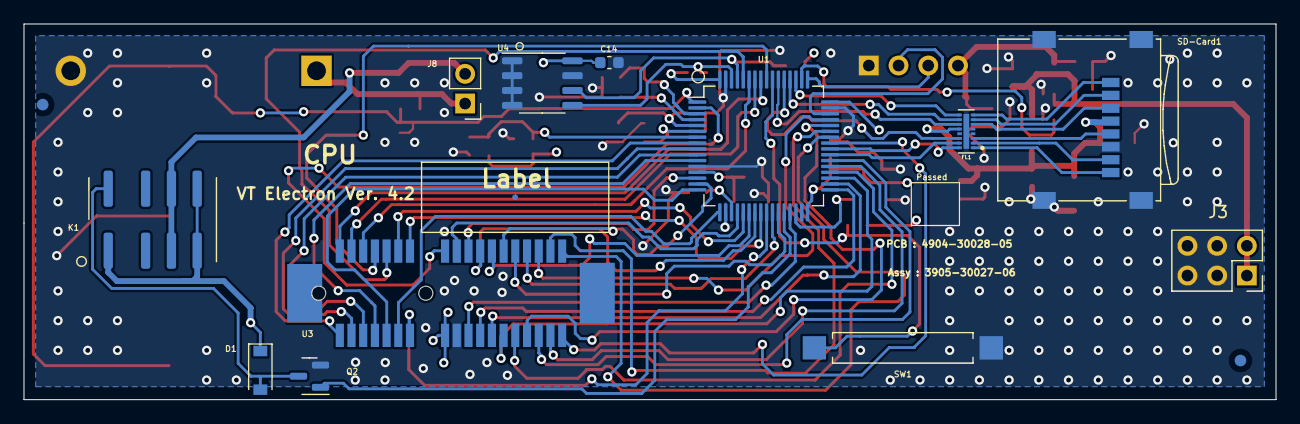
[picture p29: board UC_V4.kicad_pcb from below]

Board: 4 copper layers, 107.0 x 32.1 mm, 51 parts (14 on the bottom side), 68 nets.

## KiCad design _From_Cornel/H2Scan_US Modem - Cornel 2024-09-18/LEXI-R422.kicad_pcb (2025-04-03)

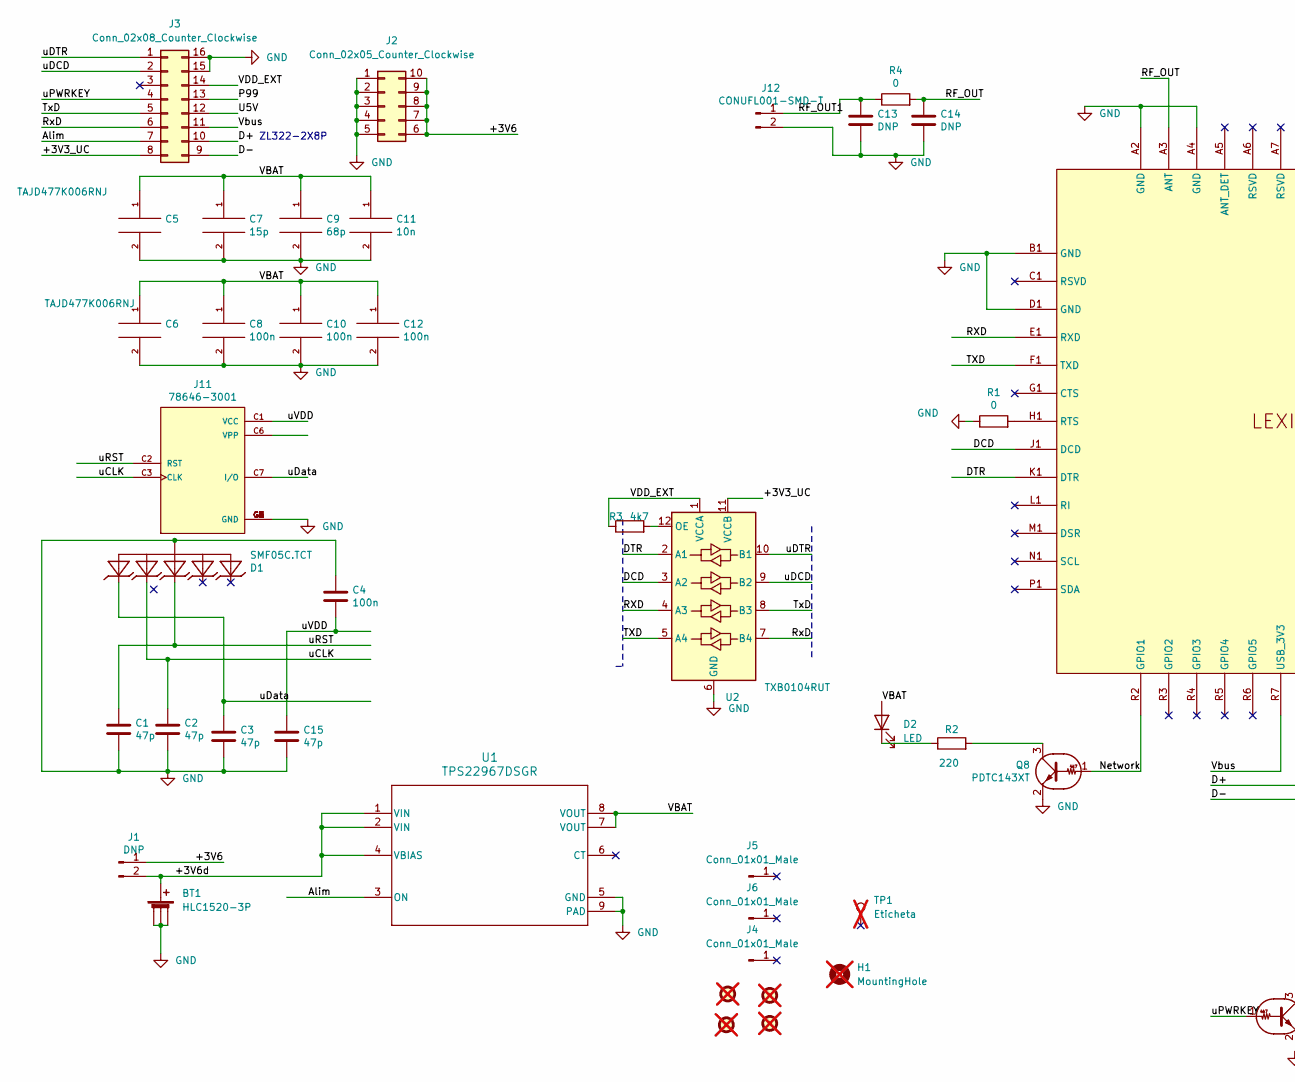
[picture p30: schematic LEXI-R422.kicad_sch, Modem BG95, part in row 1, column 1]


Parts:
BT1: HLC1520-3P
C1, C2, C3, C15: 47p; C_0603_1608Metric
C4, C8, C10, C12: 100n; C_0603_1608Metric
C5, C6: TAJD477K006RNJ; CP_EIA-7361-38_AVX-V_Pad2.18x3.30mm_HandSolder
C7: 15p; C_0603_1608Metric
C9: 68p; C_0603_1608Metric
C11: 10n; C_0603_1608Metric
C13, C14: DNP; C_0603_1608Metric
D1: SMF05C.TCT; SC70-6
D2: LED; LED_0805_2012Metric
FB1: FerriteBead_Small; L_Walsin_WLFM201209x
FID1, FID2, FID3, FID4: Fiducial; Fiducial_1mm_Mask2mm; not fitted
H1: MountingHole; MountingHole_2.5mm Simpla; not fitted
J1: DNP; PinHeader_1x02_P2.54mm_Vertical_MOD
J2: Conn_02x05_Counter_Clockwise; PinHeader_2x05_P2.54mm_Vertical_SMD_MOD
J3: Conn_02x08_Counter_Clockwise; PinHeader_2x08_P2.54mm_Vertical_SMD_MOD
J4, J5, J6: Conn_01x01_Male; TestPoint_Pad_5.1x5.1mm
J11: 78646-3001; MOLEX_78646-3001; DIGI-KEY_PART_NUMBER WM9364CT-ND
J12: CONUFL001-SMD-T; U.FL_Molex_MCRF_73412-0110_Vertical
M1: LEXI-R422; LEXI; Manufacturer P/N *
Q3, Q8: PDTC143XT; SOT-23
R1, R4: 0; R_0603_1608Metric
R2: 220; R_0603_1608Metric
R3: 4k7; R_0603_1608Metric
TP1: Eticheta; not fitted
TP4: TestPoint; TestPoint_Pad_D1.5mm; not fitted
U1: TPS22967DSGR; WSON-8-1EP_2x2mm_P0.5mm_EP0.9x1.6mm_ThermalVias
U2: TXB0104RUT; Texas_R_PUQFN-N12

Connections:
/+3V3_UC: J3.8, U2.11 (VCCB)
/+3V6: J1.1, J2.6, J2.7, J2.8, J2.9, J2.10
/+3V6d: BT1.1 (+), J1.2, U1.1 (VIN), U1.2 (VIN), U1.4 (VBIAS)
/Alim: J3.7, U1.3 (ON)
/D+: J3.10, M1.R8 (USB_D-)
/D-: J3.9, M1.R9 (USB_D+)
/DCD: M1.J1 (DCD), U2.3 (A2)
/DTR: M1.K1 (DTR), U2.2 (A1)
/Network: M1.R2 (GPIO1), Q8.1 (B)
/P99: J3.13, M1.J5 (RSVD)
/PWRKEY: M1.P15 (PWR_CTRL), Q3.3 (C), TP4.1
/RF_OUT: C14.1, M1.A3 (ANT), R4.2
/RF_OUT1: C13.1, J12.1, R4.1
/RXD: M1.E1 (RXD), U2.4 (A3)
/RxD: J3.6, U2.7 (B4)
/TXD: M1.F1 (TXD), U2.5 (A4)
/TxD: J3.5, U2.8 (B3)
/U5V: J3.12, M1.R10 (USB_5V0)
/VBAT: C5.1, C6.1, C7.1, C8.1, C9.1, C10.1, C11.1, C12.1, D2.2 (A), FB1.2, U1.7 (VOUT), U1.8 (VOUT)
/VBAT_F: FB1.1, M1.A12 (VCC), M1.A13 (VCC), M1.A14 (VCC)
/VDD_EXT: J3.14, M1.A11 (V_INT), R3.1, U2.1 (VCCA)
/Vbus: J3.11, M1.R7 (USB_3V3)
/uCLK: C2.1, D1.5, J11.C3 (CLK), M1.K15 (SIM_CLK)
/uDCD: J3.2, U2.9 (B2)
/uDTR: J3.1, U2.10 (B1)
/uData: C3.1, D1.6, J11.C7 (I/O), M1.J15 (SIM_IO)
/uPWRKEY: J3.4, Q3.1 (B)
/uRST: C1.1, D1.4, J11.C2 (RST), M1.L15 (SIM_RST)
/uVDD: C4.2, C15.1, J11.C1 (VCC), M1.H15 (VSIM)
GND: BT1.2 (-), BT1.3 (-), BT1.4 (-), C1.2, C2.2, C3.2, C4.1, C5.2, C6.2, C7.2, C8.2, C9.2, C10.2, C11.2, C12.2, C13.2, C14.2, C15.2, D1.2, J2.1, J2.2, J2.3, J2.4, J2.5, J3.15, J3.16, J11.C5 (GND), J11.G1 (GND), J11.G2 (GND), J11.G3 (GND), J11.G4 (GND), J11.G5 (GND), J11.G6 (GND), J12.2, M1.A2 (GND), M1.A4 (GND), M1.B1 (GND), M1.C3 (GND), M1.C7 (GND), M1.C8 (GND), M1.C9 (GND), M1.C10 (GND), M1.C11 (GND), M1.C13 (GND), M1.D1 (GND), M1.E6 (GND), M1.E7 (GND), M1.E8 (GND), M1.E9 (GND), M1.E10 (GND), M1.E11 (GND), M1.E13 (GND), M1.F6 (GND), M1.F7 (GND), M1.F8 (GND), M1.F9 (GND), M1.F10 (GND), M1.F11 (GND), M1.F13 (GND), M1.G6 (GND), M1.G7 (GND), M1.G8 (GND), M1.G9 (GND), M1.G10 (GND), M1.G11 (GND), M1.G13 (GND), M1.H6 (GND), M1.H7 (GND), M1.H8 (GND), M1.H9 (GND), M1.H10 (GND), M1.H11 (GND), M1.H13 (GND), M1.J6 (GND), M1.J7 (GND), M1.J8 (GND), M1.J9 (GND), M1.J10 (GND), M1.J11 (GND), M1.J13 (GND), M1.K6 (GND), M1.K7 (GND), M1.K8 (GND), M1.K9 (GND), M1.K10 (GND), M1.K11 (GND), M1.K13 (GND), M1.L3 (GND), M1.L5 (GND), M1.L6 (GND), M1.L7 (GND), M1.L8 (GND), M1.L9 (GND), M1.L10 (GND), M1.L11 (GND), M1.L13 (GND), M1.N3 (GND), M1.N5 (GND), M1.N7 (GND), M1.N8 (GND), M1.N9 (GND), M1.N10 (GND), M1.N11 (GND), M1.N13 (GND), Q3.2 (E), Q8.2 (E), R1.1, U1.5 (GND), U1.9 (PAD), U2.6 (GND)
unnamed: D2.1 (K), R2.1
unnamed: M1.H1 (RTS), R1.2
unnamed: Q8.3 (C), R2.2
unnamed: R3.2, U2.12 (OE)

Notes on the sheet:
ZL322-2X8P



Board: 4 copper layers, 72.0 x 25.5 mm, 43 parts (15 on the bottom side), 34 nets.

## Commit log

2025-04-03 ADE filess upload
    [3901-30030-04 - PCA, Scavenger - ADE Channel (ADE) ver 4.3.xlsx, 3901-30030-05_3D -- ADE_Main_V4.4.step, 3901-30030-05_BOM -- ADE_Main_V4.4.csv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]
2025-04-03 ADE-Aux filess upload
    [3906-00010-02_3D -- ADE_Aux_V4.4.step, 3906-00010-02_BOM -- ADE Aux_ver 4.4.xlsx, 3906-00010-02_BOM -- ADE_Aux_V4.4.csv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]
2025-04-03 BG95 filess upload
    [3902-30029-07 - PCA, Scavenger - Communications (GSM), BG95, Ver 4.4 - EUR.xlsx, 3902-30029-08 - PCA, Scavenger - Communications (GSM), BG95, Ver 4.4 - EUR.xls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]
2025-04-03 Main filess upload
    [3905-30027-06_BOM -- Main_V4.4.csv, 3905-30027-06_BOM -- Main_V4.4.xlsx, 3905-30027-06_BOM -- Main_V4.4_kl.csv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]
2025-04-03 Shield Protction filess upload
    [4905-40010-01_Main_Shield_V4.step, Main_Shield_V44.kicad_pcb, Main_Shield_V44.kicad_sch]
2025-04-03 Original Files from Cornell via email upload
    [3901-30030-05 -- ADE_Main_V4.4.step, 3901-30030-05 -- ADE_Main_V4.step, 3901-30030-05_3D -- ADE_Main_V4.4.step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]

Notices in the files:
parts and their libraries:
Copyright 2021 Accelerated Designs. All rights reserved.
